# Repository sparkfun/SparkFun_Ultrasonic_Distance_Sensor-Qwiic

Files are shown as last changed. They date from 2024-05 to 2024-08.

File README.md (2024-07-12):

SparkFun Ultrasonic Distance Sensor - TCT40 (Qwiic) 
========================================

<center>SparkFun Ultrasonic Distance Sensor - TCT40 (Qwiic)</center>

[*SparkFun Ultrasonic Distance Sensor - TCT40 (Qwiic) (SEN-24805)*](https://www.sparkfun.com/products/24805)

The SparkFun Qwiic Ultrasonic Distance Sensor, a user-friendly upgrade to the popular HC-SR04 sensor, offers non-contact distance measurement from 2cm to 400cm with an accuracy of 3mm. This sensor is designed to seamlessly integrate with the Qwiic ecosystem for I<sup>2</sup>C communication, making it a breeze to add to your existing projects and daisy-chain with other Qwiic components.

If you prefer to bypass the Qwiic connector and I2C, you can also access the VCC, Trigger, Echo, and Ground pins broken out on the board's edge. Please be aware that this ultrasonic sensor comes uncalibrated, and you will need to manipulate the raw output for your specific application.

With its wide range of applications, the SparkFun Qwiic Ultrasonic Distance Sensor is a versatile tool for robotics projects, obstacle avoidance systems, and any application that requires accurate distance measurement without physical contact. Its adaptability makes it a valuable addition to your toolkit.

Repository Contents
-------------------

* **/Documentation** - Datasheets, additional product information
* **/Enclosure** - Enclosure files 
* **/Firmware** - Default firmware on the Ultrasonic Distance Sensor -TCT40 
* **/Hardware** - Eagle design files (.brd, .sch)
* **/Production** - Production panel files (.brd)

Documentation
--------------
* **[Hookup Guide](https://docs.sparkfun.com/SparkFun_Ultrasonic_Distance_Sensor-Qwiic)** - Basic hookup guide for the SparkFun Ultrasonic Distance Sensor - TCT40 (Qwiic).
* **[Arduino Library](https://github.com/sparkfun/SparkFun_Qwiic_Ultrasonic_Arduino_Library)** - Arduino library for the SparkFun Ultrasonic Distance Sensor - TCT40 (Qwiic). 

License Information
-------------------

This product is _**open source**_! 

Please review the LICENSE.md file for license information. 

If you have any questions or concerns on licensing, please contact technical support on our [SparkFun forums](https://forum.sparkfun.com/viewforum.php?f=152).

Distributed as-is; no warranty is given.

- Your friends at SparkFun.

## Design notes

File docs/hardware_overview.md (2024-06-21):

---
icon: material/cog
---

Overall Features:

* Operating Voltage 3.3V
* Detecting Angle: 80 degrees
* Sensor range: 2cm to 400cm
* MCU on board: STM8L051F3
* 7 bit Unshifted Address: 0x2F
* Dimensions: 1.75" x 0.85"

## STM8L051F3 MCU

The 8-bit ultra-low power STM8 MCU Core provides increased processing power (up to 16 MIPS at 16 MHz) while maintaining the advantages of a CISC architecture with improved code density, a 24-bit linear addressing space and an optimized architecture for low power operations. It also features embedded data EEPROM and low power, low-voltage, single-supply program Flash memory. The device incorporates an extensive range of enhanced I/Os and peripherals, a 12-bit ADC, a real-time clock, two 16-bit timers, one 8-bit timer, as well as standard communication interfaces such as an SPI, an I<sup>2</sup>C interface, and one USART. For more information, refer to the [datasheet](assets/component_documentation/stm8l051f3-1.pdf).

<figure markdown>
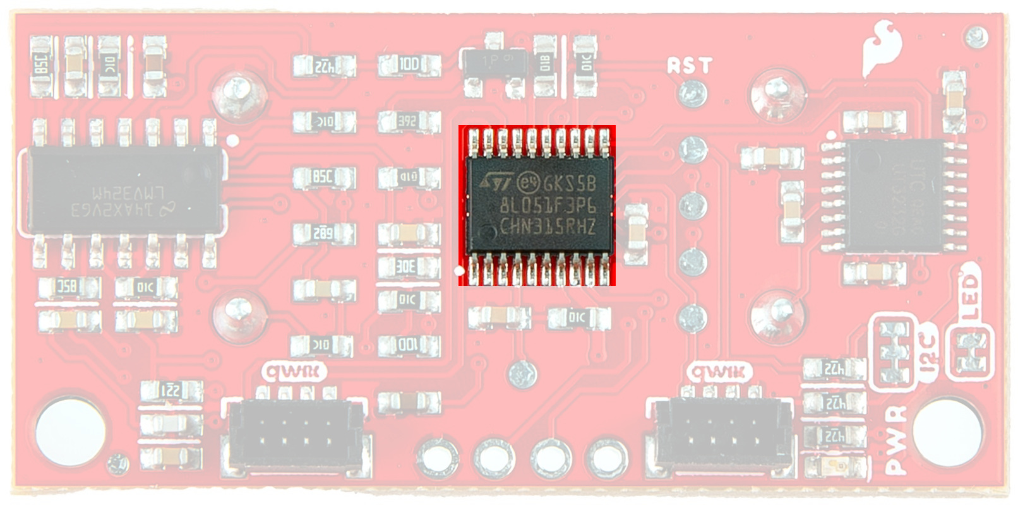
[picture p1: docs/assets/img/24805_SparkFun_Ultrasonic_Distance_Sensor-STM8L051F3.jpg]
STM8L051F3 MCU

<figcaption markdown>STM8L051F3 MCU</figcaption>
</figure>

## TCT40-16R/T

The TCT40-16R and TCT40-16T are an analog ultrasonic receiver and transmitter featuring a distance range from 2cm to 400cm meters and a beam angle of 80°. We've attached an RS232 transceiver to the transmitter to boost the signal being sent out, and the receiver goes through an LMV324 op-amp to clean up the signal coming in for optimum detection. For more information, refer to the translated datasheet [here](assets/component_documentation/TCT40-16-T-R.pdf).

<figure markdown>
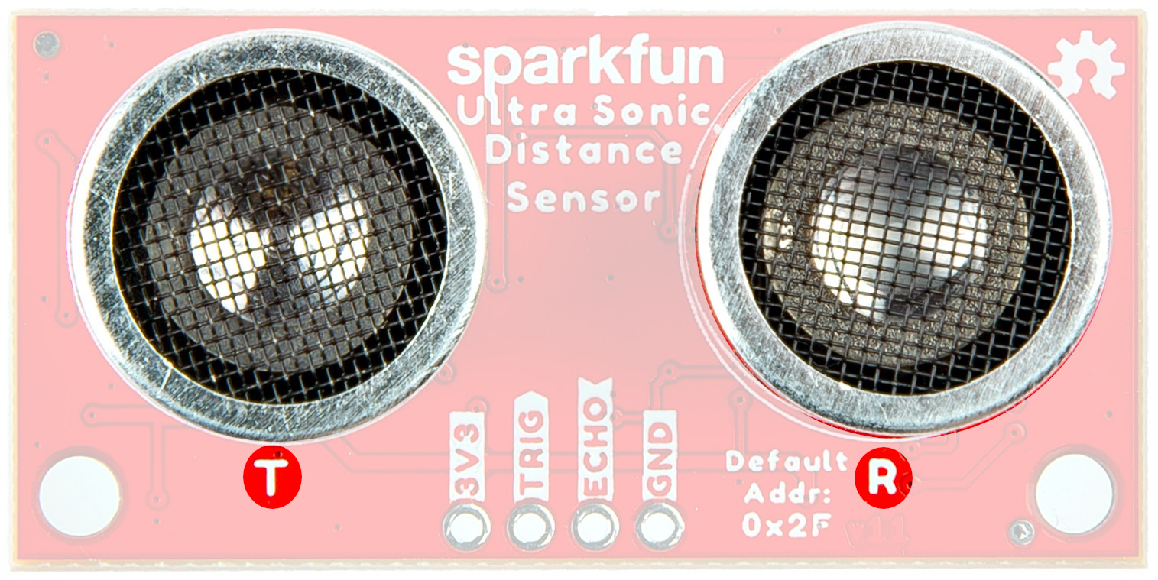
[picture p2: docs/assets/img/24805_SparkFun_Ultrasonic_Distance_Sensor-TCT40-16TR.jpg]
TCT40-16R/T

<figcaption markdown>TCT40-16R/T</figcaption>
</figure>

## Qwiic connectors

Our Qwiic Ecosystem makes sensors pretty much plug and play. There are two Qwiic connectors on the side of the Qwiic Distance Sensor board to provide power and I<sup>2</sup>C connectivity simultaneously. The default I<sup>2</sup>C address is 0x2F. The `updateAddress()` function allows you to change the I<sup>2</sup>C address to any address from 0x08 to 0x7F. More information on our Qwiic Ecosystem [can be found here](https://www.sparkfun.com/qwiic).  

<figure markdown>
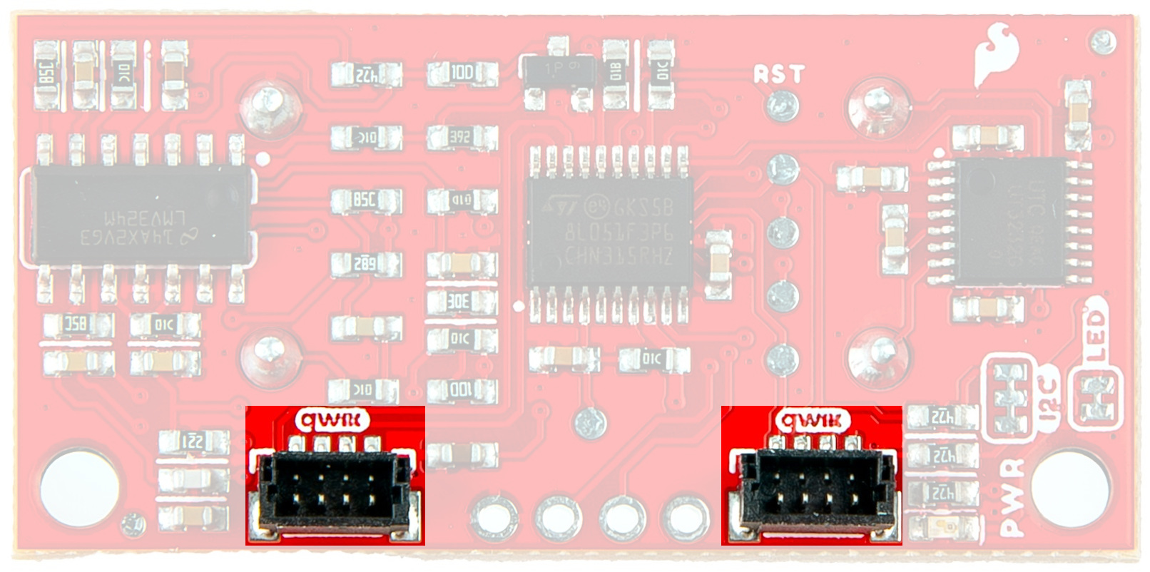
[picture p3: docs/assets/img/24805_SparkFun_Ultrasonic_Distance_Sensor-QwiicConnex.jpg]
Qwiic connectors

<figcaption markdown>Qwiic connectors</figcaption>
</figure>

## Power

Ideally, power will be supplied via the Qwiic connectors on either side of the board. Alternatively, power can be supplied through the pins along the bottom side of the board labeled `3V3` and `GND`. The input voltage range should be between <b>1.8</b>-<b>3.6V</b>. 

<figure markdown>
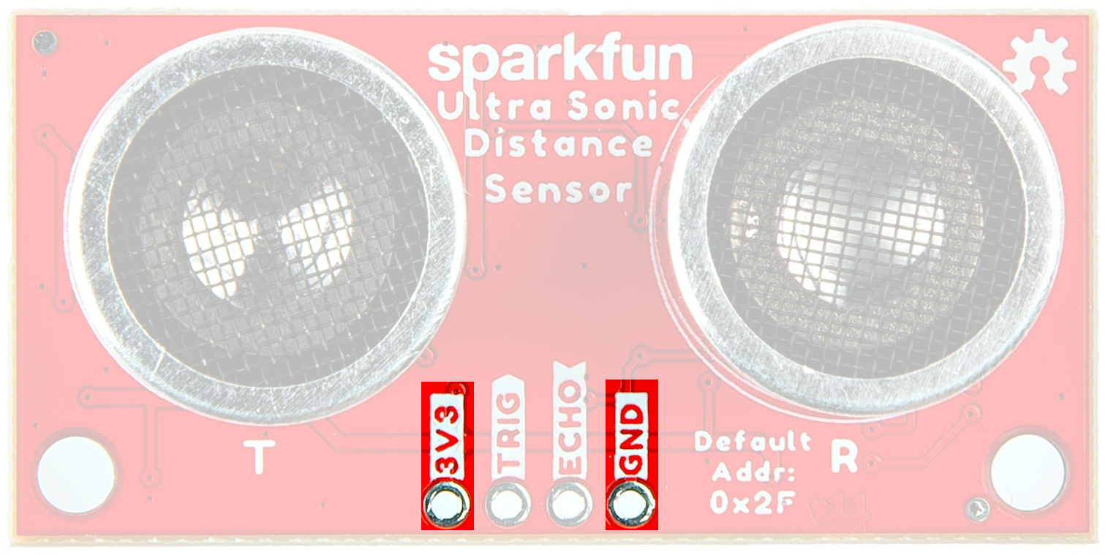
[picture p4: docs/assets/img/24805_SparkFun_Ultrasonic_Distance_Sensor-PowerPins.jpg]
Power Pins

<figcaption markdown>Power Pins</figcaption>
</figure>

## Trigger and Echo Pins

The Trigger and Echo pins are available as plated through holes to manually calculate the distance using the Ultrasonic Distance Sensor. To use, pull TRIG HIGH and then LOW, wait for the ECHO pin to go HIGH and then take the time in between to calculate the distance to the object. For more information on how this works, check out Example 3 in the [Arduino Library](https://github.com/sparkfun/SparkFun_Qwiic_Ultrasonic_Arduino_Library). 

<figure markdown>
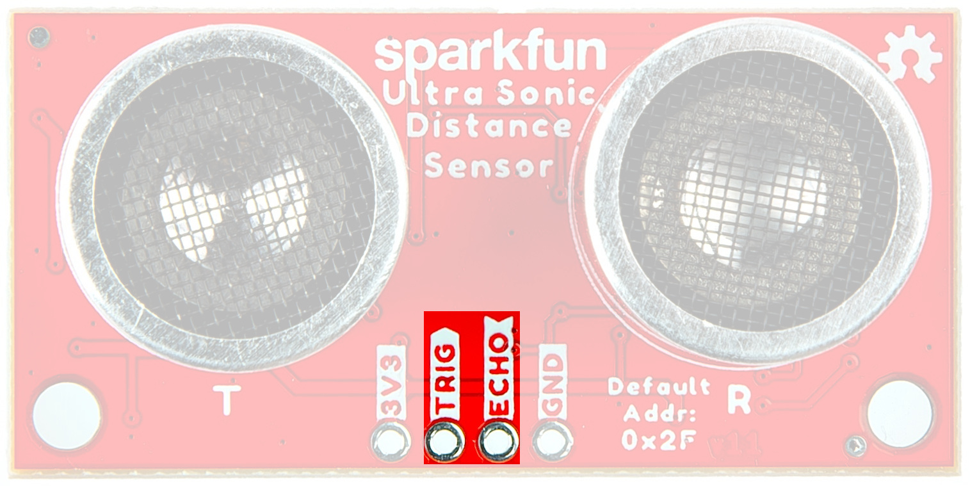
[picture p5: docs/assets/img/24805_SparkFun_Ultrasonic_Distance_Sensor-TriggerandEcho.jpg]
Trigger and Echo Pins

<figcaption markdown>Trigger and Echo Pins</figcaption>
</figure>

## Testpoint Pads

We've provided a number of open pads on the back of the board:

### I2C Pads

Should you wish to avoid using the Qwiic connectors, you can use these two pads (along with the power PTH pins) to still take advantage of the I<sup>2</sup>C communication protocols. 

<figure markdown>
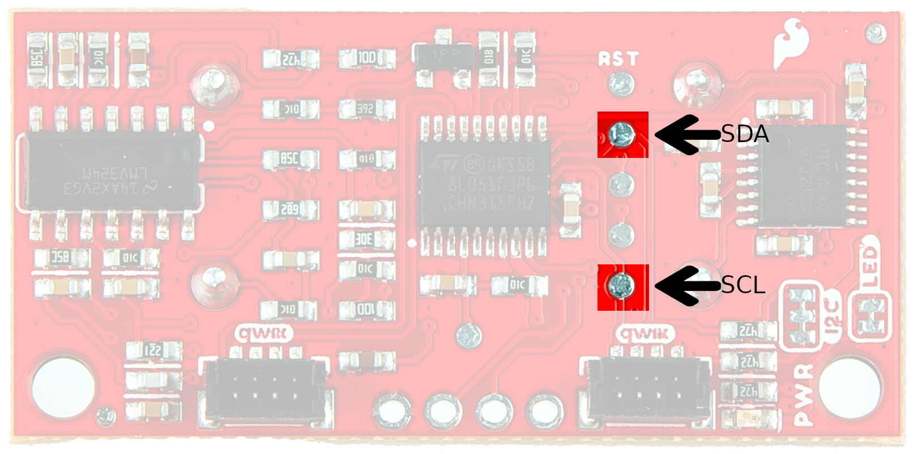
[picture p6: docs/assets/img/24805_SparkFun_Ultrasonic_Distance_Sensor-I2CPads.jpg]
I2C Testpoint Pads

<figcaption markdown>I<sup>2</sup>C Testpoint Pads</figcaption>
</figure>

### Single Wire Interface Module (SWIM)

SWIM, INT, and NRST are all part of the "Single Wire Interface Module (SWIM)" used for programming the onboard STM8 microcontroller and for most users, can be effectively ignored. For those who wish to dive into the deep end and tweak the firmware, these pads are available. Requirements include ST Visual Develop (the ST Progamming Software bundled with Visual Develop), a COSMIC compiler license, and a USB to SWIM adapter.

<figure markdown>
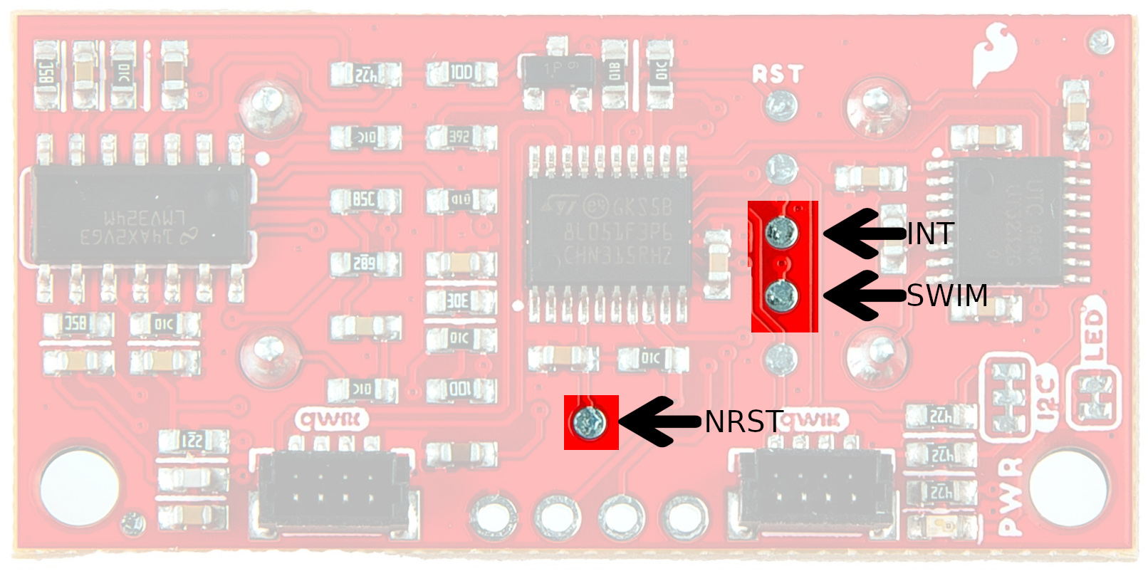
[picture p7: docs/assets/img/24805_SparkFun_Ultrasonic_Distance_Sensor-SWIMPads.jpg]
SWIM Testpoint Pads

<figcaption markdown>SWIM Testpoint Pads</figcaption>
</figure>

### ADDR_RST 

ADDR_RST resets the address to 0x2F. 

<figure markdown>
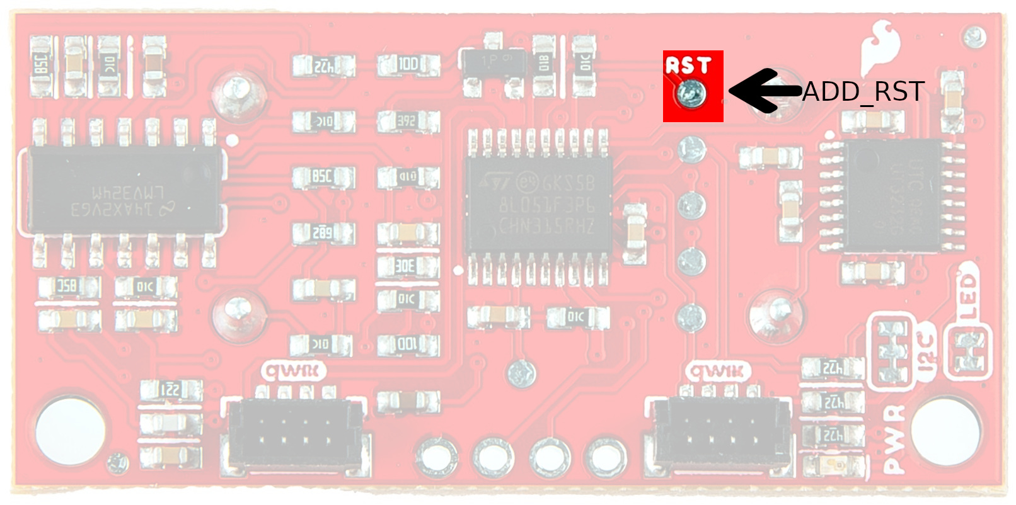
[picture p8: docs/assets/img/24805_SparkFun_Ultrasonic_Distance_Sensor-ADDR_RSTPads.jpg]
ADDR_RST Testpoint Pad

<figcaption markdown>ADDR_RST Testpoint Pad</figcaption>
</figure>

## Jumpers

??? note "Never modified a jumper before?"
	Check out our <a href="https://learn.sparkfun.com/tutorials/664">Jumper Pads and PCB Traces tutorial</a> for a quick introduction!
	<p align="center">
		<a href="https://learn.sparkfun.com/tutorials/664">
		Tutorial's thumbnail<br>
        How to Work with Jumper Pads and PCB Traces</a>
	</p>

### LED Jumper

If you are concerned about power consumption, need to run dark, or you just don't like LEDs, cut the traces here to disconnect the Power LED from, you guessed it, power. 

<figure markdown>
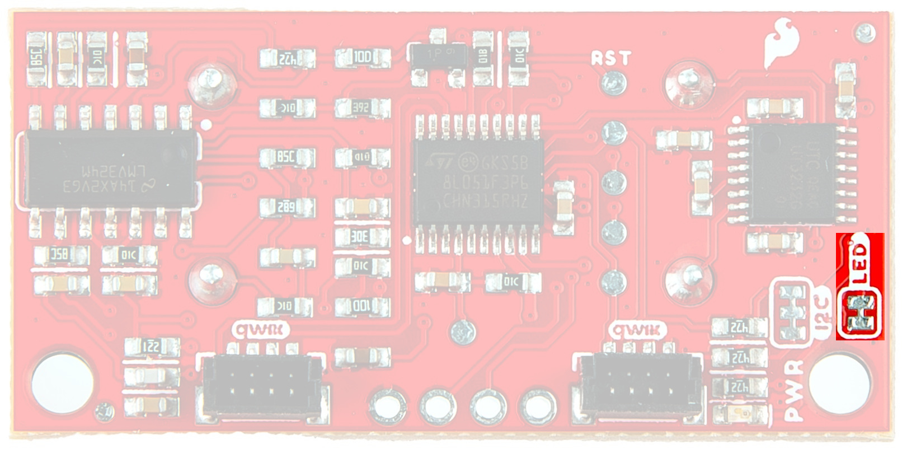
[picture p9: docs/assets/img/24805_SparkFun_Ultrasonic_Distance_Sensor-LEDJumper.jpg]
LED jumper

<figcaption markdown>LED Jumper</figcaption>
</figure>

### I<sup>2</sup>C

The Qwiic Ultrasonic Distance Sensor has built-in 2.2k pull-up resistors on the SDA and SCL lines. These are needed for normal I<sup>2</sup>C communication. The I<sup>2</sup>C jumper has two small traces connecting the pull-ups to 3.3V. **For general use you can leave this jumper unmodified.** If you have many (over 7) devices on the I<sup>2</sup>C bus, each with their own pull up resistors, then you may want to [cut the I<sup>2</sup>C jumpers](https://learn.sparkfun.com/tutorials/how-to-work-with-jumper-pads-and-pcb-traces) to disconnect the 2.2k resistors on each Qwiic board.

<figure markdown>
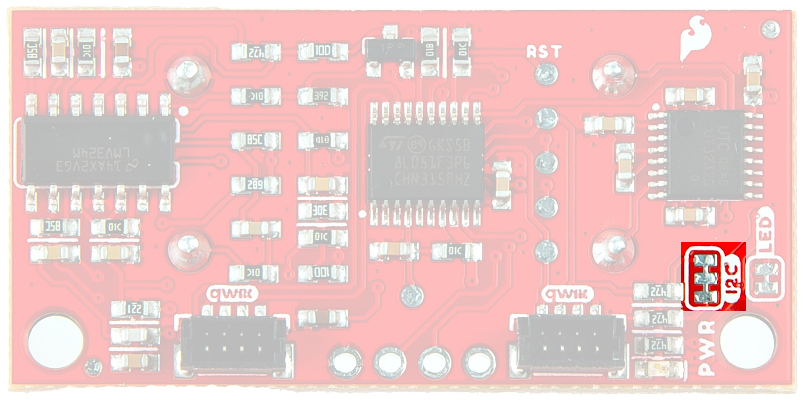
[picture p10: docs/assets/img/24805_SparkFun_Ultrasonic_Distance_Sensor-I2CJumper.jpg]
I2C jumper

<figcaption markdown>I<sup>2</sup>C jumper</figcaption>
</figure>

## Board Dimensions

The board dimensions are illustrated in the drawing below; the listed measurements are in inches.

<figure markdown>
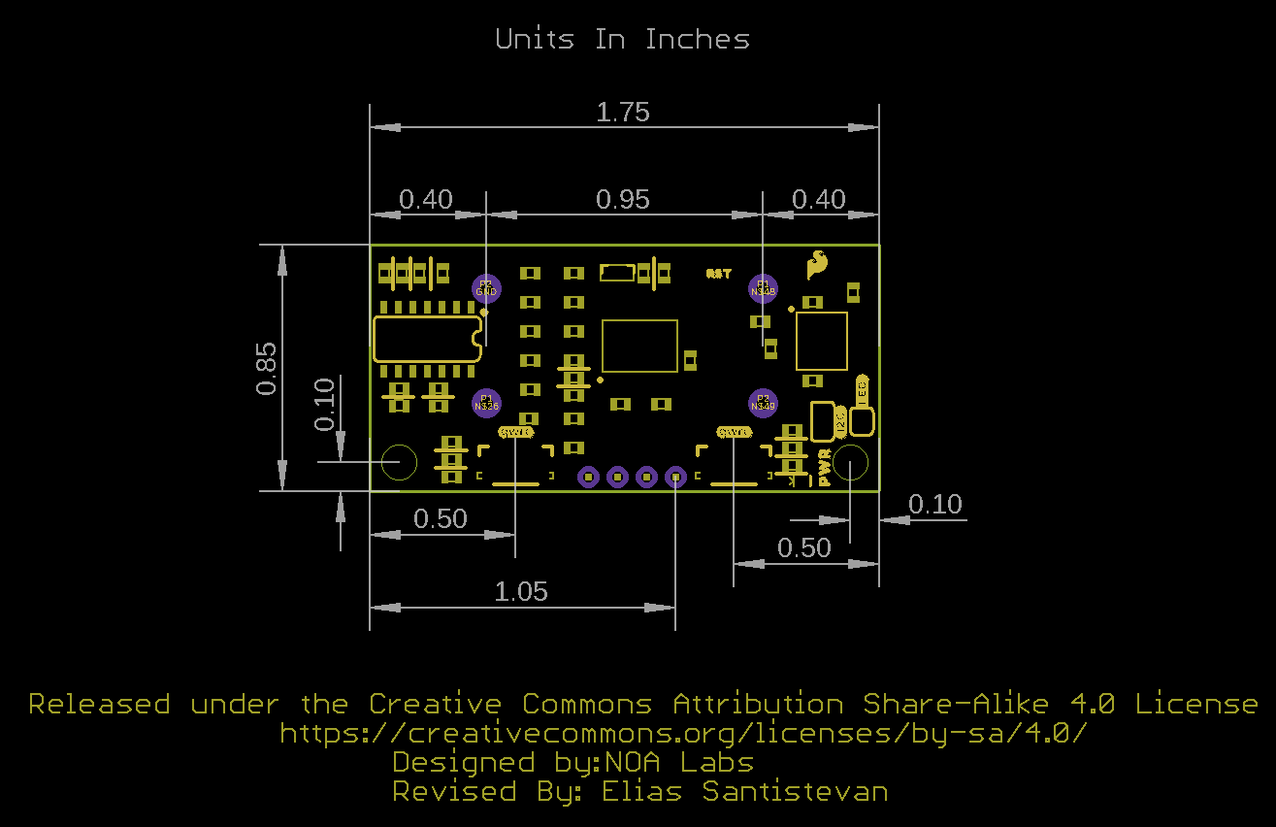
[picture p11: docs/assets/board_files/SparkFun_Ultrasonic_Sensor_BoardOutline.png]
Board measures 1.75" by 0.85"

<figcaption markdown>SparkFun Ultrasonic Sensor Board Dimensions</figcaption>
</figure>

??? tip "Need more measurements?"
	For more information about the board's dimensions, users can download the [Eagle files](SparkFun_Ultrasonic_Sensor_EagleFiles.zip). These files can be opened in Eagle and additional measurements can be made with the dimensions tool.

	??? info ":octicons-download-16:{ .heart } Eagle - Free Download!"
		Eagle is a [CAD]("computer-aided design") program for electronics that is free to use for hobbyists and students. However, it does require an account registration to utilize the software.

		<center>
		[Download from<br>:autodesk-primary:{ .autodesk }](https://www.autodesk.com/products/eagle/free-download "Go to downloads page"){ .md-button .md-button--primary width="250px" }
		</center>
	
	??? info ":straight_ruler: Dimensions Tool"
		This video from Autodesk demonstrates how to utilize the dimensions tool in Eagle, to include additional measurements:

		<center>
		<div class="video">
		<iframe src="https://www.youtube.com/embed/dZLNd1FtNB8" title="EAGLE Dimension Tool" frameborder="0" allow="accelerometer; autoplay; clipboard-write; encrypted-media; gyroscope; picture-in-picture" allowfullscreen></iframe>
		</div>
		</center>

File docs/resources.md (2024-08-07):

<!-- This section should include all the relevant documentation and product files (Eagle files, schematic, datasheet(s), landing pages, etc. and any relevant tutorials to go beyond the Hookup Guide.) -->

For more resources related to the SparkFun Ultrasonic Distance Sensor - TCT40 (Qwiic), check out the links listed here: 

* [Product Page](https://www.sparkfun.com/products/24805)
* [Schematic](assets/board_files/SparkFun_Ultrasonic_Sensor_Schematic.pdf) (PDF)
* [Eagle Files](assets/board_files/SparkFun_Ultrasonic_Sensor_EagleFiles.zip) (ZIP)
* [Board Dimensions](assets/board_files/SparkFun_Ultrasonic_Sensor_BoardOutline.png) (PDF)
* Component Documentation
    * [STM8L051F3 MCU Datasheet](assets/component_documentation/stm8l051f3-1.pdf) (PDF)
    * [TCT40-16R/T Datasheet](assets/component_documentation/TCT40-16-T-R.pdf) (PDF)
    * [RS232 transceiver Datasheet](assets/component_documentation/sp3222eb_sp3232eb.pdf) (PDF)
* [Arduino Library GitHub Repository](https://github.com/sparkfun/SparkFun_Qwiic_Ultrasonic_Arduino_Library)
* [GitHub Hardware Respository](https://github.com/sparkfun/SparkFun_Ultrasonic_Distance_Sensor-Qwiic/)

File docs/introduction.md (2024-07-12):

---
icon: material/book-open-page-variant
---

<div class="grid cards desc" markdown>

-    <a href="https://www.sparkfun.com/products/24805">
    **SparkFun Ultrasonic Distance Sensor - TCT40 (Qwiic)**<br>
    **SKU:** SEN-24805

    ---

    <figure markdown>
    Product Thumbnail
    </figure></a>

-    The SparkFun Qwiic Ultrasonic Distance Sensor, a user-friendly upgrade to the popular HC-SR04 sensor, offers non-contact distance measurement from 2cm to 400cm with an accuracy of 3mm. This sensor is designed to seamlessly integrate with the Qwiic ecosystem for I<sup>2</sup>C communication, making it a breeze to add to your existing projects and daisy-chain with other Qwiic components.

    With its wide range of applications, the SparkFun Qwiic Ultrasonic Distance Sensor is a versatile tool for robotics projects, obstacle avoidance systems, and any application that requires accurate distance measurement without physical contact. Its adaptability makes it a valuable addition to your toolkit.

    <center>
    [Purchase from SparkFun :fontawesome-solid-cart-plus:{ .heart }](https://www.sparkfun.com/products/24805){ .md-button .md-button--primary }
    </center>

</div>

## Required Materials

To follow along with this tutorial, you will need the following materials. You may not need everything though depending on what you have. Add it to your cart, read through the guide, and adjust the cart as necessary.

<table style="border-style:none">
    <tr>
        <td>
            <a href="https://www.sparkfun.com/products/24805">
                <center>SparkFun Ultrasonic Distance Sensor - TCT40 (Qwiic)</center>
                <h3 class="title">SparkFun Ultrasonic<br /> Distance Sensor - TCT40<br />(Qwiic)</h3>
            </a>
            SEN-24805
        </td>
        <td>
            <a href=" https://www.sparkfun.com/products/10215">
                <center>USB micro-B Cable - 6 Foot</center>
                <h3 class="title">USB micro-B Cable - 6 Foot</h3>
            </a>
            CAB-10215
        </td>
<!--        <td>
            <a href="https://www.sparkfun.com/products/17153">
                <center><img src="https://cdn.sparkfun.com//assets/parts/1/6/1/3/5/17153-SparkFun_Qwiic_OLED_Display__0.91_in__128x32_-05.jpg" style="width:140px; height:140px; object-fit:contain;" alt="SparkFun Qwiic OLED Display (0.91 in., 128x32)" >
                </center>
                <h3 class="title">SparkFun Qwiic OLED Display (0.91 in., 128x32)</h3>
            </a>
            LCD-17153
        </td>-->
        <td>
            <a href="https://www.sparkfun.com/products/14427">
                <center>Qwiic Cable - 100mm
                </center>
                <h3 class="title">Qwiic Cable - 100mm</h3>
            </a>
            PRT-14427
        </td>
        <td>
            <a href="https://www.sparkfun.com/products/15123">
                <center>SparkFun RedBoard Qwiic
                </center>
                <h3 class="title">SparkFun RedBoard Qwiic</h3>
            </a>
            DEV-15123
        </td>
    </tr>
</table>

## Suggested Reading

Below are a few tutorials that may help users familiarize themselves with various aspects of the board.

<div class="grid cards hide col-4" markdown align="center">

-   <a href="https://learn.sparkfun.com/tutorials/how-to-solder-through-hole-soldering">
    <figure markdown>
    How to Solder: Through-Hole Soldering
    </figure>
    </a>
    <a href="https://learn.sparkfun.com/tutorials/how-to-solder-through-hole-soldering">**How to Solder: Through-Hole Soldering**
    </a>

-   <a href="https://learn.sparkfun.com/tutorials/82">
    <figure markdown>
    I2C
    </figure>
    </a>
    <a href="https://learn.sparkfun.com/tutorials/82">**I2C**
    </a>

-   <a href="https://learn.sparkfun.com/tutorials/terminal-basics">
    <figure markdown>
    SPI
    </figure>
    </a>
    <a href="https://learn.sparkfun.com/tutorials/terminal-basics">**Serial Terminal Basics**
    </a>
</div>

<center>
<div align="center">
    <div style="top:5px;left:5px;background-color:Gray;position:relative">
        <div style="top:-5px;left:-5px;background-color:#ffffff;position:relative;border:1px solid black;">
            <a href="https://www.sparkfun.com/qwiic">Qwiic Connect System</a>
        </div>
    </div>
</div>
</center>

The SparkFun Ultrasonic Distance Sensor - TCT40 (Qwiic) takes advantage of the [Qwiic connect system](https://www.sparkfun.com/qwiic). We recommend familiarizing yourself with the **Logic Levels** and **I<sup>2</sup>C** tutorials.  Click on the banner above to learn more about [Qwiic products](https://www.sparkfun.com/qwiic).

<center>
    <iframe width="600" height="327" src="https://www.youtube.com/embed/x0RDEHqFIF8" title="SparkFun's Qwiic Connect System" frameborder="0" allow="accelerometer; autoplay; clipboard-write; encrypted-media; gyroscope; picture-in-picture" allowfullscreen></iframe>
</center>

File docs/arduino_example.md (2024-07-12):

---
icon: simple/arduino
---

Now that we've installed the Arduino library, it's time to upload our first sketch to make sure everything is working properly.

###Example 1

This first example just does some basic measurements. To find Example 1, go to **File** > **Examples** > **SparkFun Qwiic Ultrasonic Arduino Library** > **Example1_BasicReadings**:

<figure markdown>
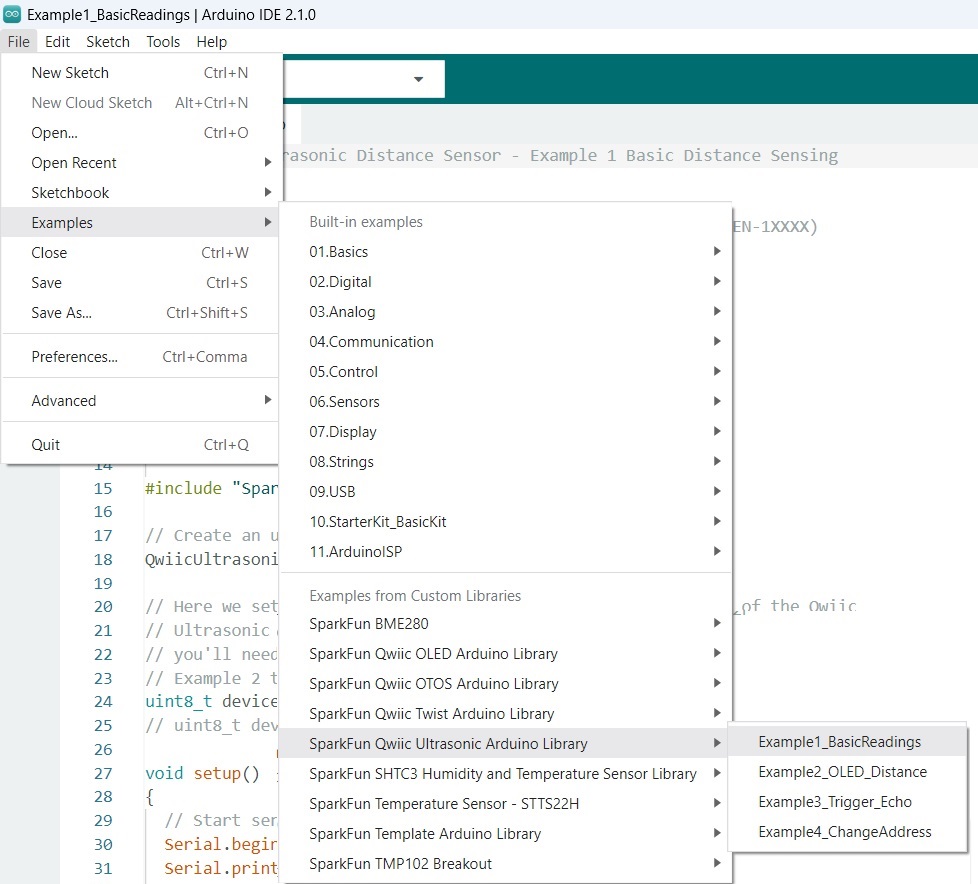
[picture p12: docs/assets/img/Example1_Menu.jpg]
Ultrasonic Arduino Example 1

<figcaption markdown>Finding Example 1</figcaption>
</figure>

Alternatively, you can expand the link below and copy and paste the code into a shiny new Arduino sketch:

??? "Example 1 Arduino Code"
	```
	--8<-- "https://raw.githubusercontent.com/sparkfun/SparkFun_Qwiic_Ultrasonic_Arduino_Library/main/examples/Example1_BasicReadings/Example1_BasicReadings.ino"
	```

Make sure you've selected the correct board and port in the Tools menu and then hit the upload button. Once the code has finished uploading, go ahead and open a [Serial Monitor](https://learn.sparkfun.com/tutorials/terminal-basics). You should see something similar to the following.

<figure markdown>
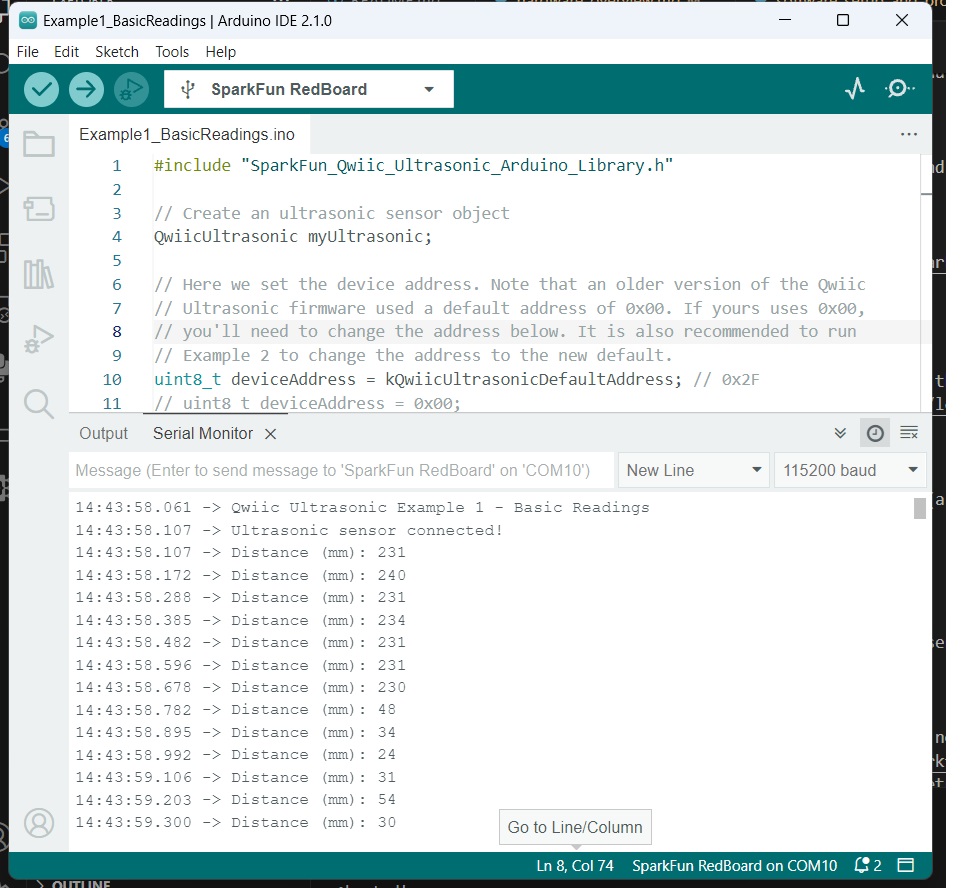
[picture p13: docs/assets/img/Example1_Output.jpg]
Ultrasonic Distance Sensor Arduino Example 1 Output

<figcaption markdown>Example 1 Output</figcaption>
</figure>

Note the output change when the mouse is moved closer to the sensor.

### Example 2

Let's add in an LCD screen to display our measurements. For this example you will need another [Qwiic Cable](https://www.sparkfun.com/products/14427) and the [SparkFun Qwiic OLED Display (0.91 in., 128x32)](https://www.sparkfun.com/products/24606).

To display the sensor readings on the connected Qwiic OLED, we will need to install the SparkFun Qwiic OLED library. You can install this library to automatically in the Arduino IDE's Library Manager by searching for "**SparkFun Qwiic OLED**". Or you can manually download it from the [GitHub repository](https://github.com/sparkfun/SparkFun_Qwiic_OLED_Arduino_Library).

<center>
	[Download the SparkFun Qwiic OLED Library (ZIP)](https://github.com/sparkfun/SparkFun_Qwiic_OLED_Arduino_Library/archive/refs/heads/main.zip){ .md-button .md-button--primary }
</center>

To find Example 2, go to **File** > **Examples** > **SparkFun Qwiic Ultrasonic Arduino Library** > **Example2_OLED_Distance**:

<figure markdown>
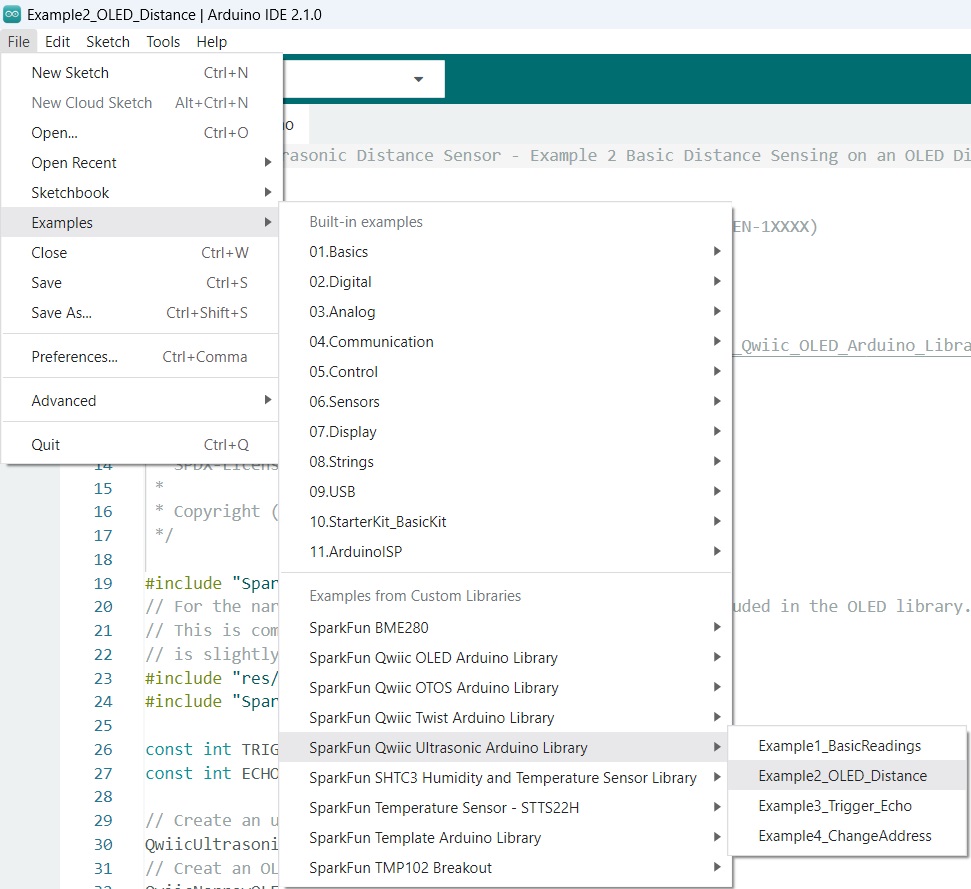
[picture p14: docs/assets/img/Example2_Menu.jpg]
Ultrasonic Arduino Example 2

<figcaption markdown>Finding Example 2</figcaption>
</figure>

Alternatively, you can expand the link below and copy and paste the code into a shiny new Arduino sketch:

??? "Example 2 Arduino Code"
	```
	--8<-- "https://raw.githubusercontent.com/sparkfun/SparkFun_Qwiic_Ultrasonic_Arduino_Library/main/examples/Example2_OLED_Distance/Example2_OLED_Distance.ino"
	```

We have code, now let's hookup the hardware! The Qwiic system makes this example quite literally plug and play. Use Qwiic cables to make your hardware setup look like this:

<figure markdown>
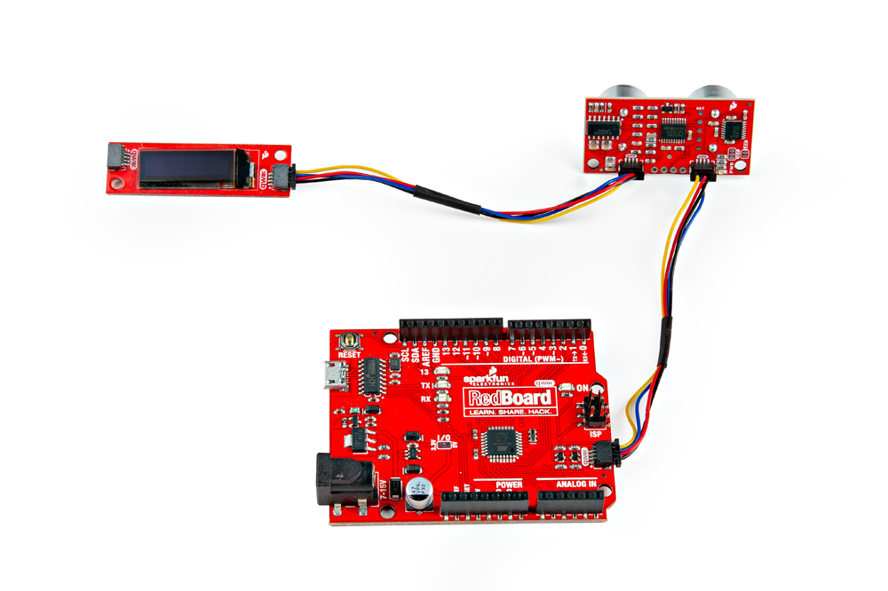
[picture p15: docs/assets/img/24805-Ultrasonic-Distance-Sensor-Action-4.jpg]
Example 2 Hardware Hookup

<figcaption markdown>Example 2 Hardware Hookup</figcaption>
</figure>

Make sure you've selected the correct board and port in the Tools menu and then hit the upload button. Once the code has finished uploading, you should see something similar to the following.

<figure markdown>
Oh no! A dinosaur is approaching distance sensor and now it's only 61mm away!
<figcaption markdown>Run away!</figcaption>
</figure>

Try moving an object (like your hand or a dinosaur) closer to the sensor - notice the output of the OLED shows you how close the object is! Grr. Rawr!

### Going Further

There are more examples in the Arduino Library that allow you to change the I<sup>2</sup>C address or use the Trigger and Echo Pins. Feel free to check them out!

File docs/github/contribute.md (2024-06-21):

# Contribute: Make an Augmentation!
Spot an improvement opportunity? Feel free to contribute to our open-source design and documentation. 

## :material-file-document-multiple:&nbsp;Improve our Documentation
All of this documentation can be modified by you! Please help us make it better.

* These pages are contained in the [`docs` folder](https://github.com/sparkfun/SparkFun_Ultrasonic_Distance_Sensor-Qwiic/tree/v11_Firmware_v01/docs) of the [SparkFun Ultrasonic Distance Sensor - TCT40 (Qwiic) repository](https://github.com/sparkfun/SparkFun_Ultrasonic_Distance_Sensor-Qwiic/tree/v11_Firmware_v01).

<!-- ### :material-source-pull:&nbsp;Submit a Correction -->
### Submit a Correction

1. With a GitHub account, [fork this repository](https://github.com/sparkfun/SparkFun_Ultrasonic_Distance_Sensor-Qwiic/fork).
2. Add your corrections or improvements to the markdown file.
3. File a pull request with your changes, and enjoy making the ~~words~~ ~~worlds~~ world a better place.
	* Once received, the documentation specialist will automatically be notified.
	* We will review your suggested improvements to make sure they are correct and fit within our documentation standards.

## :material-cog:&nbsp;Improve our Hardware Design
All of our designs are open-source! Please help us make it better.

* Our board design files are contained in the [`Hardware` folder](https://github.com/sparkfun/SparkFun_Ultrasonic_Distance_Sensor-Qwiic/tree/v11_Firmware_v01/Hardware) of the [SparkFun Ultrasonic Distance Sensor - TCT40 (Qwiic) repository](https://github.com/sparkfun/SparkFun_Ultrasonic_Distance_Sensor-Qwiic/tree/v11_Firmware_v01).

<!-- ### :material-source-pull:&nbsp;Submit a Design Enhancement -->
### Submit a Design Enhancement

1. With a GitHub account, [fork this repository](https://github.com/sparkfun/SparkFun_Ultrasonic_Distance_Sensor-Qwiic/fork).
2. Add your design augmentation(s)
3. File a pull request with your changes, and enjoy making the ~~words~~ ~~worlds~~ world a better place.
	1. Once received, the engineer in charge of the original design will automatically be notified.
	2. We will review your suggested improvement(s) to verify that they are within our board design standards and meet our product design requirements.
	3. If approved, we will flag these changes for our next board revision. Congrats! 🍻

		!!! info
			Even if your suggestion is accepted, these changes may not be immediately available for purchase. We may have to cycle through our current product inventory first.

## Contributors&nbsp;:clap:
Let's provide some recognition to the contributors for this project!

GitHub Contributors Image
<br>


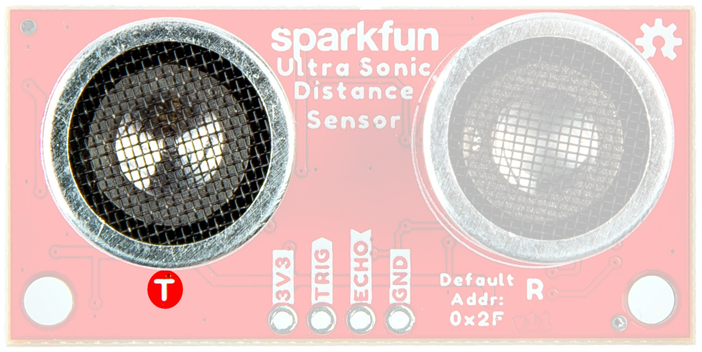
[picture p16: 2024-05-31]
docs/assets/img/24805_SparkFun_Ultrasonic_Distance_Sensor-Transmit.jpg

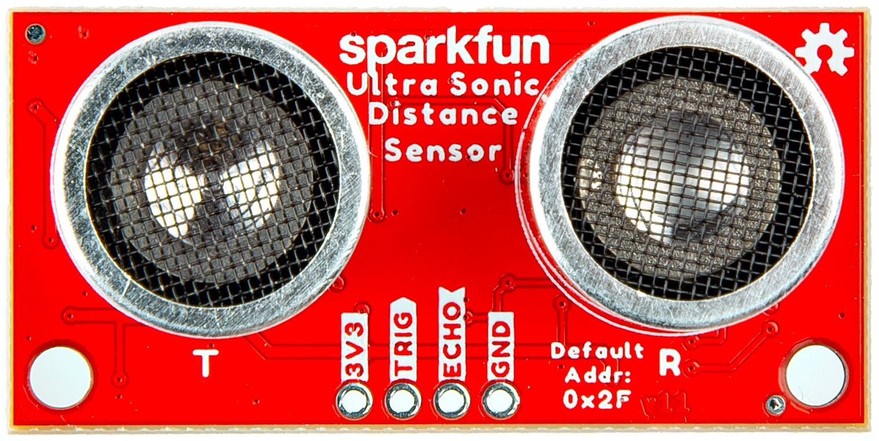
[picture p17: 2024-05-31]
docs/assets/img/SEN-24805-Ultrasonic-Distance-Sensor-Front-High-Res.jpg

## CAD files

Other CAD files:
Firmware/firmware_v01.stp

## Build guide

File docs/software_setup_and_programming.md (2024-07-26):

---
icon: simple/arduino
---

!!! attention
	If this is your first time using Arduino, please review our tutorial on [installing the Arduino IDE](https://learn.sparkfun.com/tutorials/installing-arduino-ide). If you have not previously installed an Arduino library, please check out our [installation guide](https://learn.sparkfun.com/tutorials/installing-an-arduino-library).

SparkFun has written a library to work with the SparkFun Ultrasonic Distance Sensor Qwiic Board. You can obtain this library <!--through the Arduino Library Manager by searching for "Ultrasonic" and installing the latest version. If you prefer--> by clicking on the button below, or by downloading it from the [GitHub Repository](https://github.com/sparkfun/SparkFun_Qwiic_Ultrasonic_Arduino_Library).

<center>
	[SparkFun Ultrasonic Distance Sensor Qwiic Arduino Library GitHub](https://github.com/sparkfun/SparkFun_Qwiic_Ultrasonic_Arduino_Library/archive/refs/heads/main.zip){ .md-button .md-button--primary }
</center>

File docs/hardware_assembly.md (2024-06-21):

---
icon: fontawesome/solid/screwdriver-wrench
---

Using the Qwiic system, assembling the hardware is simple. Connect the RedBoard to one of the Ultrasonic Distance Sensor Qwiic ports using your Qwiic cables. Then connect the RedBoard to your computer via the MicroUSB cable and voila! You're ready to rock! 

<figure markdown>
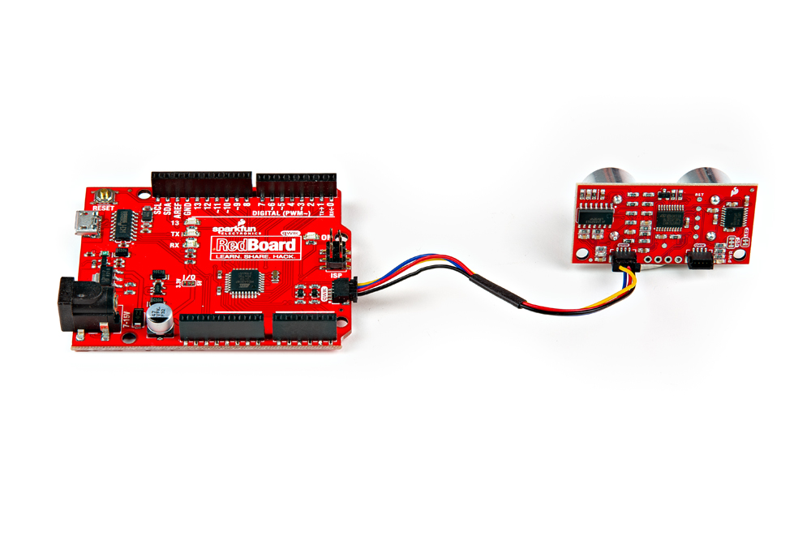
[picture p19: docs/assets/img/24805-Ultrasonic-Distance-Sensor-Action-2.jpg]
Ultrasonic Distance Sensor Connected to Programming

<figcaption markdown>Ultrasonic Distance Sensor Connected to Programming</figcaption>
</figure>

If you don't want to use the Qwiic system, there are Plated Through Holes on the side of the board that you can solder headers to. 

??? note "New to soldering?"
	If you have never soldered before or need a quick refresher, check out our [How to Solder: Through-Hole Soldering](https://learn.sparkfun.com/tutorials/how-to-solder-through-hole-soldering) guide.

	<div class="grid cards col-4" markdown  align="center">

	-   <a href="https://learn.sparkfun.com/tutorials/5">
		<figure markdown>
		Tutorial thumbnail
		</figure>

		---
		
		**How to Solder: Through-Hole Soldering**</a>

	</div>

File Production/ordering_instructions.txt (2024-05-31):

panel size, 104x190mm
PCB thickness, 1.6mm
number of layers, 2
soldermask color, Red
silkscreen color, White
oz copper, 1oz
finish, HASL lead free
stencils, top
pcs per panel, 16
min trace width, 0.2032mm / 0.0080in
min drill size, 0.3048mm / 0.0120in

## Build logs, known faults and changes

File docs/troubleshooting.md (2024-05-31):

---
icon: fontawesome/solid/question
---

!!! note
    <span class="glyphicon glyphicon-question-sign" aria-hidden="true"></span>
        <strong> Not working as expected and need help? </strong> <br /><br />

    If you need technical assistance and more information on a product that is not working as you expected, we recommend heading on over to the <a href="https://www.sparkfun.com/technical_assistance">SparkFun Technical Assistance</a> page for some initial troubleshooting. <br /><br />

    <div style="text-align: center"><a href="https://www.sparkfun.com/technical_assistance" target="sfe_technical_assistance" class="md-button">SparkFun Technical Assistance Page</a></div>

    If you don't find what you need there, the <a href="https://forum.sparkfun.com/index.php">SparkFun Forums</a> are a great place to find and ask for help. If this is your first visit, you'll need to <a href="https://forum.sparkfun.com/ucp.php?mode=register">create a Forum Account</a> to search product forums and post questions.<br /><br />

    <div style="text-align: center"><a href="https://forum.sparkfun.com/ucp.php?mode=register" class="md-button">Create New Forum Account</a>&nbsp;&nbsp;&nbsp;<a href="https://forum.sparkfun.com/index.php" class="md-button md-button--primary">Log Into SparkFun Forums</a></div>

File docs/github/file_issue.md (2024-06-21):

# Did we make a mistake?

Spot something wrong? Please let us know. 

<!-- Technical Assistance Box -->
!!! warning "Need Help?"
    If you need technical assistance or more information on a product that is not working as you expected, we recommend heading on over to the [SparkFun Technical Assistance](https://www.sparkfun.com/technical_assistanc) page for some initial troubleshooting. This **Submit Issues** page is not where users should seek assistance.

    <center>
    [SparkFun Technical Assistance Page](https://www.sparkfun.com/technical_assistance){ .md-button .md-button--primary }
    </center>
    
    If you can't find what you need there, the [SparkFun Forums](https://forum.sparkfun.com/index.php) is a great place to search the product forums and ask questions.
    
    !!! info "Account Registration Required"
        For your first visit to our forum, you'll need to create a [Forum Account](https://forum.sparkfun.com/ucp.php?mode=register) to post questions.

## Discrepancies in the Documentation

All of our documentation can be modified by you! Please help us make it better.

* The documentation files for these pages are contained in the [`docs` folder](https://github.com/sparkfun/SparkFun_Ultrasonic_Distance_Sensor-Qwiic/tree/v11_Firmware_v01/docs) of the [SparkFun Ultrasonic Distance Sensor - TCT40 (Qwiic) repository](https://github.com/sparkfun/SparkFun_Ultrasonic_Distance_Sensor-Qwiic/tree/v11_Firmware_v01).

### 🔍 Spot something wrong?

If a section of the documentation is incorrect, please [open an issue](https://github.com/sparkfun/SparkFun_Ultrasonic_Distance_Sensor-Qwiic/issues) and let us know.

### Do you have a suggested correction?

1. With a GitHub account, [fork this repository](https://github.com/sparkfun/SparkFun_Ultrasonic_Distance_Sensor-Qwiic/fork).
2. Add your correction(s) or improvement(s) to the markdown file(s)
3. File a pull request with your changes, and enjoy making the ~~words~~ ~~worlds~~ world a better place.
	* Once received, the documentation specialist will automatically be notified.
	* We will review your suggested improvement(s) to make sure they are correct and fit within our documentation standards.

## Problems in the Hardware Design

All of our designs are open-source! Please help us make it better.

* Our board design files are contained in the [`Hardware` folder](https://github.com/sparkfun/SparkFun_Ultrasonic_Distance_Sensor-Qwiic/tree/v11_Firmware_v01/Hardware) of the [SparkFun Ultrasonic Distance Sensor - TCT40 (Qwiic) repository](https://github.com/sparkfun/SparkFun_Ultrasonic_Distance_Sensor-Qwiic/tree/v11_Firmware_v01).

### Does something not make sense? 🤔

If part of the design is confusing, please [open an issue](https://github.com/sparkfun/SparkFun_Ultrasonic_Distance_Sensor-Qwiic/issues) and let us know.

### Did we forget to include an important function of the board? 🤦

If part of the board's functionality is missing, please [open an issue](https://github.com/sparkfun/SparkFun_Ultrasonic_Distance_Sensor-Qwiic/issues) and file a feature request.

!!! tip "Design Considerations"
	Please keep in mind that we may intentionally exclude certain functions of the board to meet our product design requirements.
	
	* *For example, our Qwiic Micro boards are intended to fit on a small board layout and only use I<sup>2</sup>C communication; therefore, we may not have the SPI and interrupt pins available for users.*

### Do you wish to contribute directly to improving the board design?

1. With a GitHub account, [fork this repository](https://github.com/sparkfun/SparkFun_Ultrasonic_Distance_Sensor-Qwiic/fork).
2. Add your design augmentation(s)
3. File a pull request with your changes, and enjoy making the ~~words~~ ~~worlds~~ world a better place.
	1. Once received, the engineer in charge of the original design will automatically be notified.
	2. We will review your suggested improvement(s) to verify that they are within our board design standards and meet our product design requirements.
	3. If approved, we will flag these changes for our next board revision. Congrats! 🍻

		!!! info
			Even if your suggestion is accepted, these changes may not be immediately available for purchase. We may have to cycle through our current product inventory first.

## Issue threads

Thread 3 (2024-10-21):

Ultrasonic hangs with certain processors

edspark, 2024-10-21:
Relevant information can be found [here in the forum post](https://community.sparkfun.com/t/tct40-ultrasonic-sensor-only-reads-0/61107). May be an issue with the firmware and it may not.

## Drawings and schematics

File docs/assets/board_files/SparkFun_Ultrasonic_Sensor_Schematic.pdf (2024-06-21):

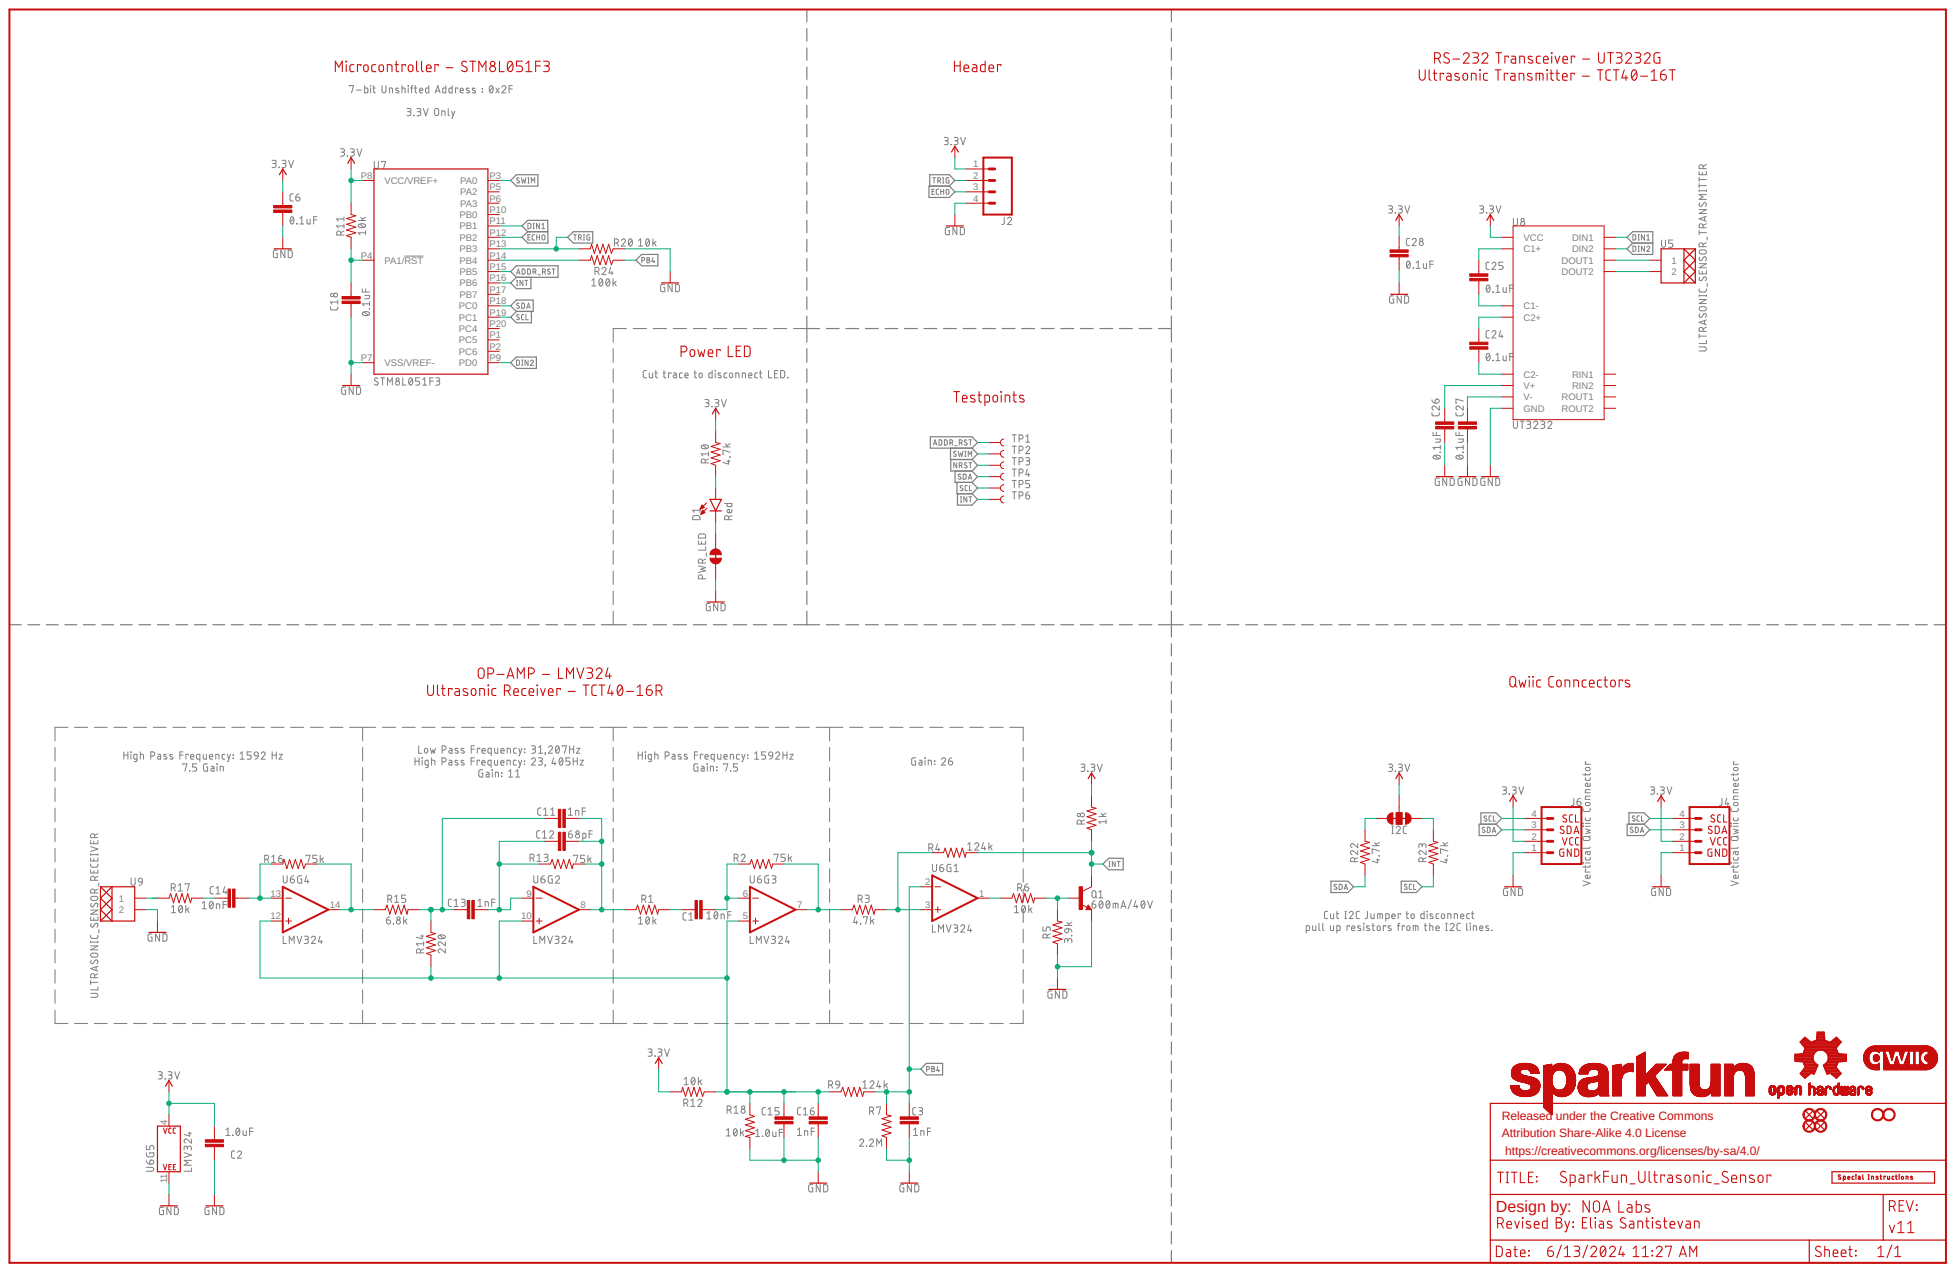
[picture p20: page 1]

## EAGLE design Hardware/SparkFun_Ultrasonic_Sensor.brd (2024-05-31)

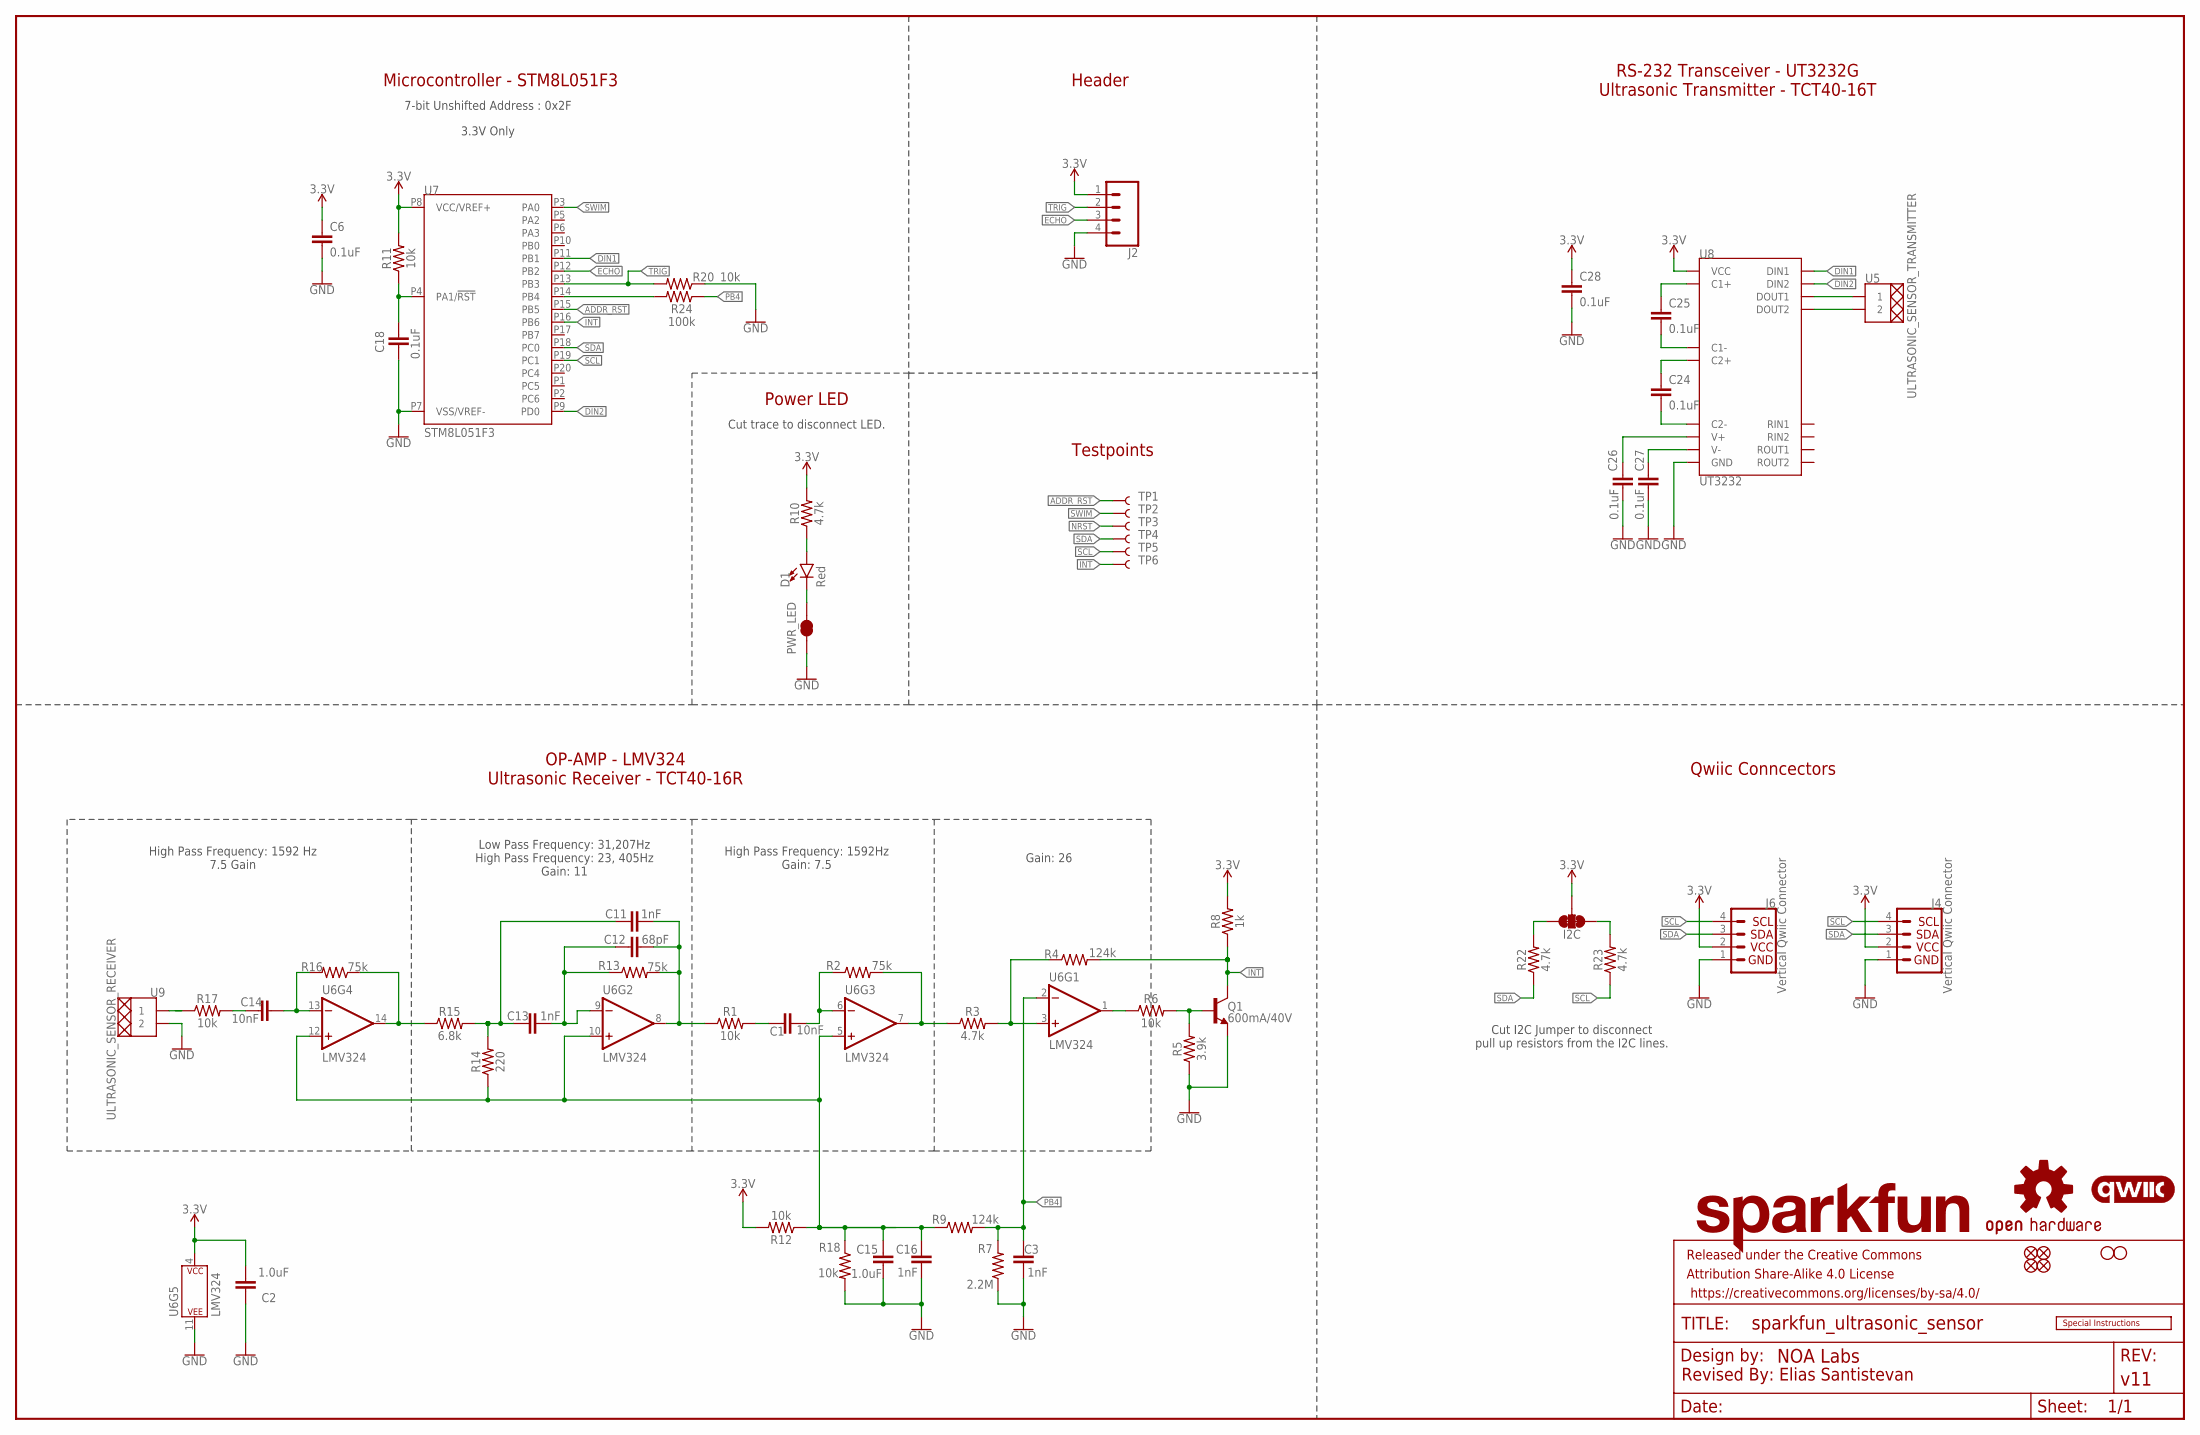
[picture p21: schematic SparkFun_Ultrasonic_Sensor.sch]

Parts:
C1, C14: 10nF; 0603
C2, C15: 1.0uF; 0603
C3, C11, C13, C16: 1nF; 0603
C6, C18, C24, C25, C26, C27, C28: 0.1uF; 0603
C12: 68pF; 0603
D1: Red; LED-0603
FD1, FD2, FD3, FD4: FIDUCIAL1X2; FIDUCIAL-1X2
FRAME1: FRAME-LEDGER; CREATIVE_COMMONS
H1, H2: STAND-OFFTIGHT; STAND-OFF-TIGHT
I2C: JUMPER-SMT_3_2-NC_TRACE_SILK; SMT-JUMPER_3_2-NC_TRACE_SILK
J2: CONN_041X04_NO_SILK_NO_POP; 1X04_NO_SILK
J4, J6: Vertical Qwiic Connector; JST04_1MM_VERT
LOGO1: SPECIAL_INSTRUCTIONS-ORDERING; ORDERING_INSTRUCTIONS
LOGO2: SFE_LOGO_NAME.1_INCH; SFE_LOGO_NAME_.1
LOGO3: QWIIC_LOGO_3MM; QWIIC_3MM
LOGO4: OSHW-LOGOS; OSHW-LOGO-S
PWR_LED: JUMPER-SMT_2_NC_TRACE_SILK; SMT-JUMPER_2_NC_TRACE_SILK
Q1: 600mA/40V; SOT23-3
R1, R6, R11, R12, R17, R18, R20: 10k; 0603
R2, R13, R16: 75k; 0603
R3, R10, R22, R23: 4.7k; 0603
R4, R9: 124k; 0603
R5: 3.9k; 0603
R7: 2.2M; 0603
R8: 1k; 0603
R14: 220; 0603
R15: 6.8k; 0603
R24: 100k; 0603
TP1, TP2, TP3, TP4, TP5, TP6: TEST-POINT3X5; PAD.03X.05
U5: ULTRASONIC_SENSOR_TRANSMITTER; TFT40-16T
U6: LMV324; SO14
U7: STM8L051F3; TSSOP20
U8: UT3232; TSSOP16
U9: ULTRASONIC_SENSOR_RECEIVER; TCT40-16R

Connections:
3.3V: C2.2, C6.1, C28.1, I2C.2, J2.1, J4.2, J6.2, R8.2, R10.2, R11.2, R12.2, U6.4 (P$V+), U7.P8 (VCC/VREF+), U8.P16 (VCC)
ADDR_RST: TP1.1, U7.P15 (PB5)
DIN1: U7.P11 (PB1), U8.P11 (DIN1)
DIN2: U7.P9 (PD0), U8.P10 (DIN2)
ECHO: J2.3, U7.P12 (PB2)
GND: C2.1, C3.2, C6.2, C15.1, C16.1, C18.2, C26.2, C27.2, C28.2, J2.4, J4.1, J6.1, PWR_LED.1, Q1.2 (E), R5.1, R7.1, R18.2, R20.1, U6.11 (P$V-), U7.P7 (VSS/VREF-), U8.P15 (GND), U9.P2 (2)
INT: Q1.3 (C), R4.2, R8.1, TP6.1, U7.P16 (PB6)
N: R24.2, U7.P14 (PB4)
unnamed: R2.2, R3.1, U6.7 (OUT)
unnamed: C1.1, R2.1, U6.6 (-IN)
unnamed: C1.2, R1.2
unnamed: R3.2, R4.1, U6.3 (+IN)
unnamed: Q1.1 (B), R5.2, R6.2
unnamed: R6.1, U6.1 (OUT)
unnamed: D1.A, R10.1
unnamed: C25.1, U8.P1 (C1+)
unnamed: C12.1, C13.1, R13.1, U6.9 (-IN)
unnamed: C11.2, C12.2, R1.1, R13.2, U6.8 (OUT)
unnamed: D1.C, PWR_LED.2
unnamed: C11.1, C13.2, R14.2, R15.2
unnamed: R15.1, R16.1, U6.14 (OUT)
unnamed: C14.1, R16.2, U6.13 (-IN)
unnamed: C14.2, R17.2
unnamed: I2C.3, R22.2
unnamed: I2C.1, R23.2
unnamed: R17.1, U9.P1 (1)
unnamed: C15.2, C16.2, R9.1, R12.1, R14.1, R18.1, U6.5 (+IN), U6.10 (+IN), U6.12 (+IN)
unnamed: C25.2, U8.P3 (C1-)
unnamed: C24.1, U8.P4 (C2+)
unnamed: C24.2, U8.P5 (C2-)
unnamed: C27.1, U8.P6 (V-)
unnamed: C26.1, U8.P2 (V+)
unnamed: U5.P1 (1), U8.P14 (DOUT1)
unnamed: U5.P2 (2), U8.P7 (DOUT2)
NRST: C18.1, R11.1, TP3.1, U7.P4 (PA1/!RST!)
PB4: C3.1, R7.2, R9.2, R24.1, U6.2 (-IN)
SCL: J4.4, J6.4, R23.1, TP5.1, U7.P19 (PC1)
SDA: J4.3, J6.3, R22.1, TP4.1, U7.P18 (PC0)
SWIM: TP2.1, U7.P3 (PA0)
TRIG: J2.2, R20.2, U7.P13 (PB3)

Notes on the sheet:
Revised By: Elias Santistevan
Microcontroller - STM8L051F3
Testpoints
RS-232 Transceiver - UT3232G Ultrasonic Transmitter - TCT40-16T
OP-AMP - LMV324 Ultrasonic Receiver - TCT40-16R
Qwiic Conncectors
Header
Cut I2C Jumper to disconnect pull up resistors from the I2C lines.
7-bit Unshifted Address : 0x2F
3.3V Only
Power LED
Cut trace to disconnect LED.
High Pass Frequency: 1592 Hz 7.5 Gain
Low Pass Frequency: 31,207Hz High Pass Frequency: 23, 405Hz Gain: 11
High Pass Frequency: 1592Hz Gain: 7.5
Gain: 26

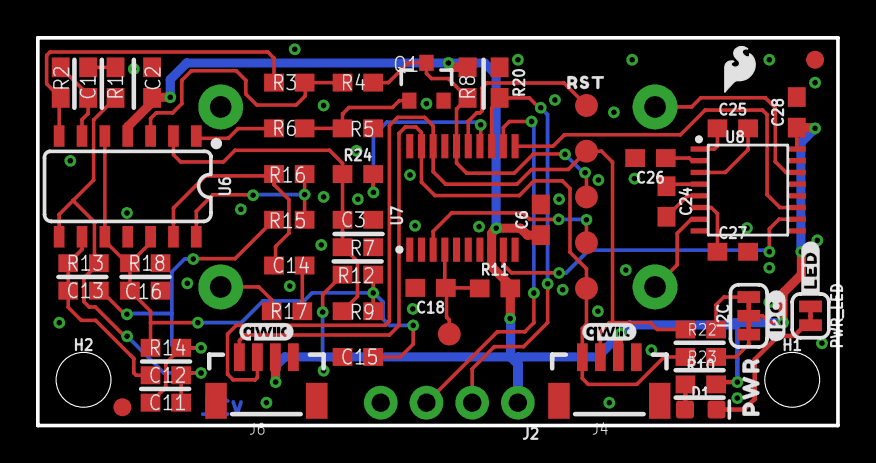
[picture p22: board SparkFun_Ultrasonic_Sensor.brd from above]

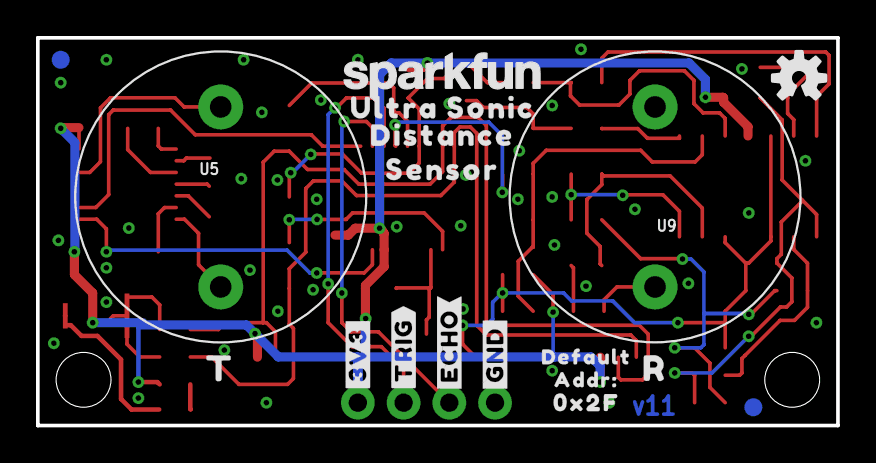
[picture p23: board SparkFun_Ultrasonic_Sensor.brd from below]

Board: 2 copper layers, 44.5 x 21.5 mm, 85 parts (18 on the bottom side), 40 nets.

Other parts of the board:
U$1: #ECHO#0
U$2: #TRIG#1
U$3: #GND#4
U$4: #3V3#2
U$5: QWIIC_3MM
U$6: SFE_LOGO_FLAME_.1
U$7: #I2C#16
U$8: T103
U$9: R104
U$10: DISTANCE101
U$11: ULTRA_SONIC100
U$12: SENSOR102
U$13: DEFAULT129
U$14: ADDR#130
U$15: 0X2F131
U$16: PWR17
U$17: #LED#15
U$18: RST132

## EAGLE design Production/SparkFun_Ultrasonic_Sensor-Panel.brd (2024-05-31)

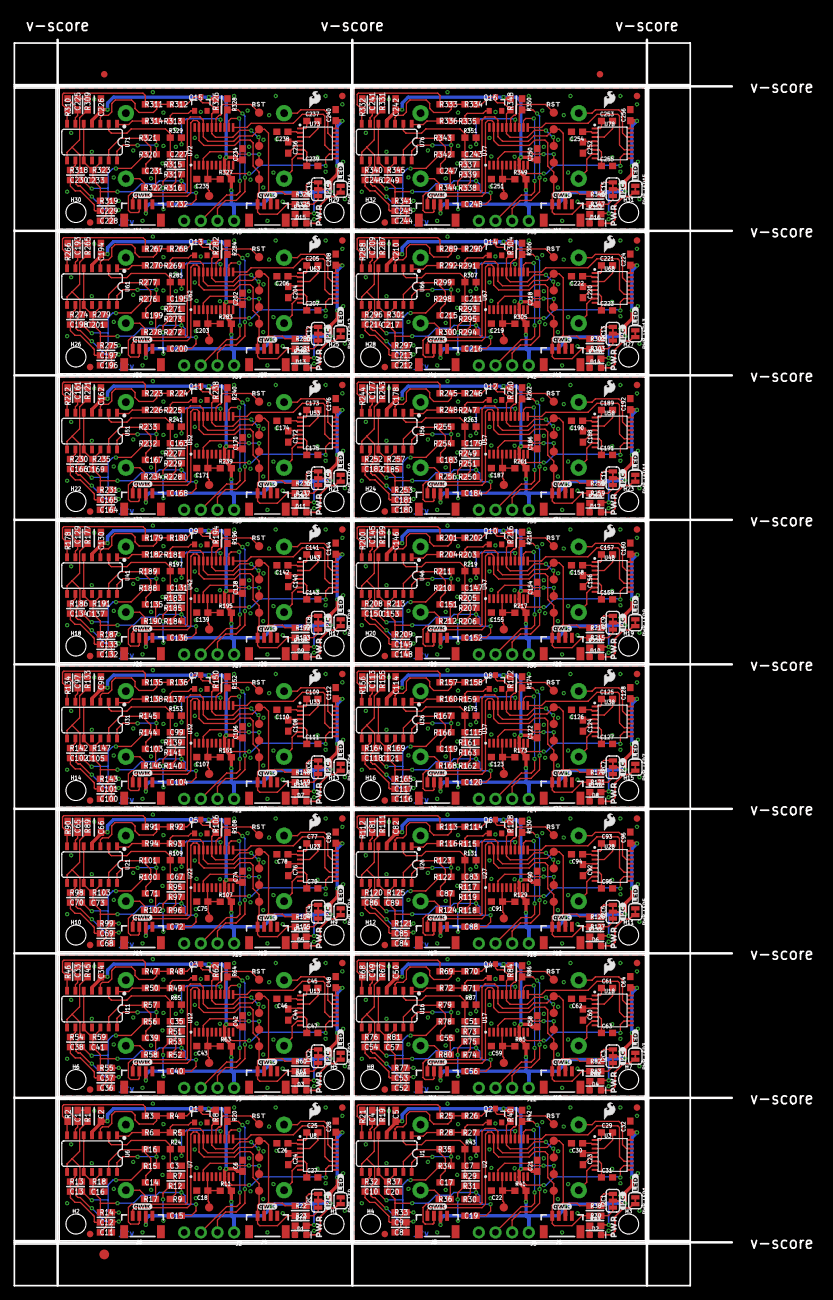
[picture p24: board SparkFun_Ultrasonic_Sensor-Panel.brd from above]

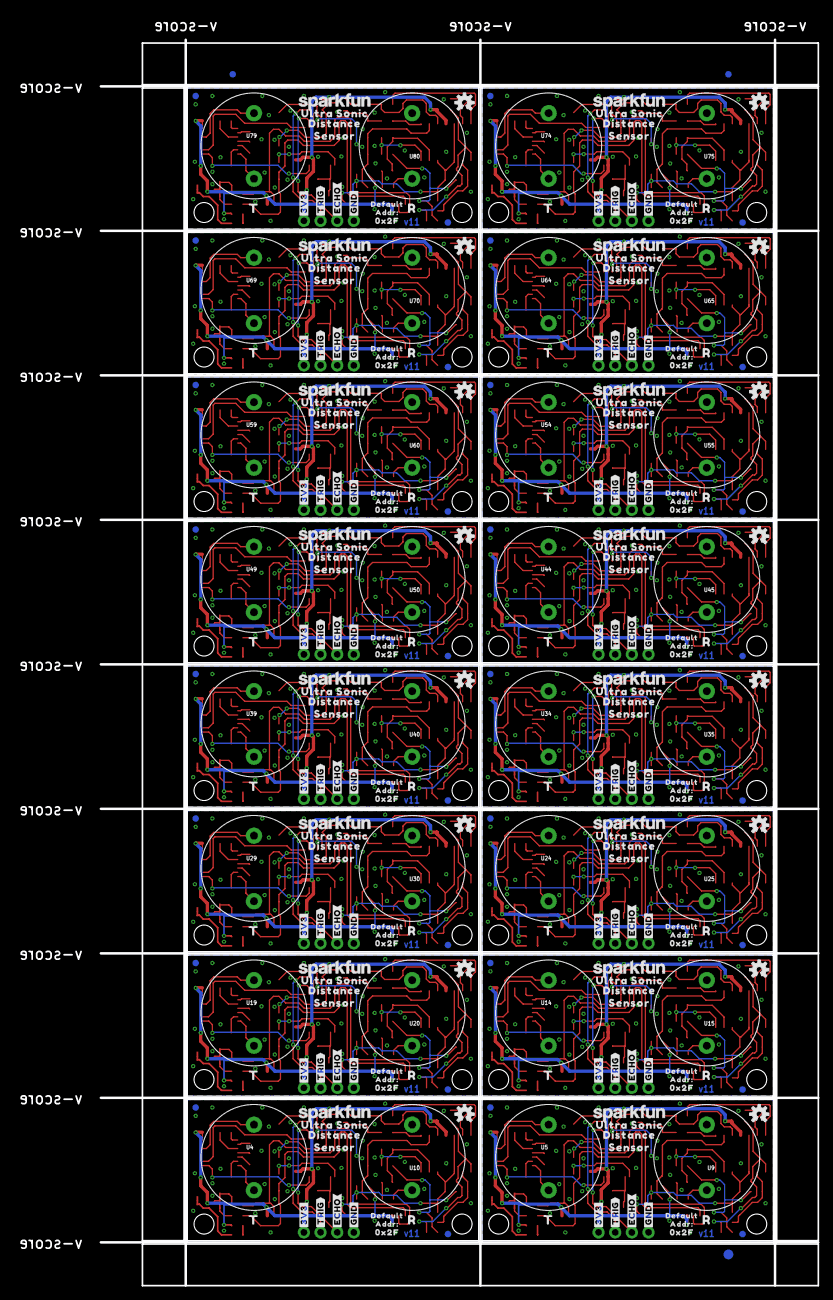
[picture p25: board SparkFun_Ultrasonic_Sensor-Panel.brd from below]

Board: 2 copper layers, 109.5 x 190.1 mm, 1334 parts (291 on the bottom side), 640 nets.

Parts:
C1, C4, C14, C17, C33, C39, C49, C55, C65, C71, C81, C87, C97, C103, C113, C119, C129, C135, C145, C151, C161, C167, C177, C183, C193, C199, C209, C215, C225, C231, C241, C247: 10nF; 0603
C2, C5, C15, C19, C34, C40, C50, C56, C66, C72, C82, C88, C98, C104, C114, C120, C130, C136, C146, C152, C162, C168, C178, C184, C194, C200, C210, C216, C226, C232, C242, C248: 1.0uF; 0603
C3, C7, C8, C10, C11, C13, C16, C20, C35, C36, C38, C41, C51, C52, C54, C57, C67, C68, C70, C73, C83, C84, C86, C89, C99, C100, C102, C105, C115, C116, C118, C121, C131, C132, C134, C137, C147, C148, C150, C153, C163, C164, C166, C169, C179, C180, C182, C185, C195, C196, C198, C201, C211, C212, C214, C217, C227, C228, C230, C233, C243, C244, C246, C249: 1nF; 0603
C6, C18, C21, C22, C23, C24, C25, C26, C27, C28, C29, C30, C31, C32, C42, C43, C44, C45, C46, C47, C48, C58, C59, C60, C61, C62, C63, C64, C74, C75, C76, C77, C78, C79, C80, C90, C91, C92, C93, C94, C95, C96, C106, C107, C108, C109, C110, C111, C112, C122, C123, C124, C125, C126, C127, C128, C138, C139, C140, C141, C142, C143, C144, C154, C155, C156, C157, C158, C159, C160, C170, C171, C172, C173, C174, C175, C176, C186, C187, C188, C189, C190, C191, C192, C202, C203, C204, C205, C206, C207, C208, C218, C219, C220, C221, C222, C223, C224, C234, C235, C236, C237, C238, C239, C240, C250, C251, C252, C253, C254, C255, C256: 0.1uF; 0603
C9, C12, C37, C53, C69, C85, C101, C117, C133, C149, C165, C181, C197, C213, C229, C245: 68pF; 0603
D1, D2, D3, D4, D5, D6, D7, D8, D9, D10, D11, D12, D13, D14, D15, D16: Red; LED-0603
E$1, E$2, E$3, E$4: FIDUCIAL-1X2
E$5, E$6: FIDUCIAL-1.5X3
FD1, FD2, FD3, FD4, FD5, FD6, FD7, FD8, FD9, FD10, FD11, FD12, FD13, FD14, FD15, FD16, FD17, FD18, FD19, FD20, FD21, FD22, FD23, FD24, FD25, FD26, FD27, FD28, FD29, FD30, FD31, FD32, FD33, FD34, FD35, FD36, FD37, FD38, FD39, FD40, FD41, FD42, FD43, FD44, FD45, FD46, FD47, FD48, FD49, FD50, FD51, FD52, FD53, FD54, FD55, FD56, FD57, FD58, FD59, FD60, FD61, FD62, FD63, FD64: FIDUCIAL1X2; FIDUCIAL-1X2
H1, H2, H3, H4, H5, H6, H7, H8, H9, H10, H11, H12, H13, H14, H15, H16, H17, H18, H19, H20, H21, H22, H23, H24, H25, H26, H27, H28, H29, H30, H31, H32: STAND-OFFTIGHT; STAND-OFF-TIGHT
I2C, I2C1, I2C2, I2C3, I2C4, I2C5, I2C6, I2C7, I2C8, I2C9, I2C10, I2C11, I2C12, I2C13, I2C14, I2C15: JUMPER-SMT_3_2-NC_TRACE_SILK; SMT-JUMPER_3_2-NC_TRACE_SILK
J1, J3, J4, J6, J7, J8, J10, J11, J13, J14, J16, J17, J19, J20, J22, J23, J25, J26, J28, J29, J31, J32, J34, J35, J37, J38, J40, J41, J43, J44, J46, J47: Vertical Qwiic Connector; JST04_1MM_VERT
J2, J5, J9, J12, J15, J18, J21, J24, J27, J30, J33, J36, J39, J42, J45, J48: 1X04_NO_SILK
LOGO1, LOGO2, LOGO7, LOGO10, LOGO13, LOGO16, LOGO19, LOGO22, LOGO25, LOGO28, LOGO31, LOGO34, LOGO37, LOGO40, LOGO43, LOGO46: SFE_LOGO_NAME.1_INCH; SFE_LOGO_NAME_.1
LOGO3, LOGO5, LOGO8, LOGO11, LOGO14, LOGO17, LOGO20, LOGO23, LOGO26, LOGO29, LOGO32, LOGO35, LOGO38, LOGO41, LOGO44, LOGO47: QWIIC_LOGO_3MM; QWIIC_3MM
LOGO4, LOGO6, LOGO9, LOGO12, LOGO15, LOGO18, LOGO21, LOGO24, LOGO27, LOGO30, LOGO33, LOGO36, LOGO39, LOGO42, LOGO45, LOGO48: OSHW-LOGOS; OSHW-LOGO-S
PWR_LED, PWR_LED1, PWR_LED2, PWR_LED3, PWR_LED4, PWR_LED5, PWR_LED6, PWR_LED7, PWR_LED8, PWR_LED9, PWR_LED10, PWR_LED11, PWR_LED12, PWR_LED13, PWR_LED14, PWR_LED15: JUMPER-SMT_2_NC_TRACE_SILK; SMT-JUMPER_2_NC_TRACE_SILK
Q1, Q2, Q3, Q4, Q5, Q6, Q7, Q8, Q9, Q10, Q11, Q12, Q13, Q14, Q15, Q16: 600mA/40V; SOT23-3
R1, R6, R11, R12, R17, R18, R19, R20, R28, R31, R36, R37, R41, R42, R45, R50, R53, R58, R59, R63, R64, R67, R72, R75, R80, R81, R85, R86, R89, R94, R97, R102, R103, R107, R108, R111, R116, R119, R124, R125, R129, R130, R133, R138, R141, R146, R147, R151, R152, R155, R160, R163, R168, R169, R173, R174, R177, R182, R185, R190, R191, R195, R196, R199, R204, R207, R212, R213, R217, R218, R221, R226, R229, R234, R235, R239, R240, R243, R248, R251, R256, R257, R261, R262, R265, R270, R273, R278, R279, R283, R284, R287, R292, R295, R300, R301, R305, R306, R309, R314, R317, R322, R323, R327, R328, R331, R336, R339, R344, R345, R349, R350: 10k; 0603
R2, R13, R16, R21, R32, R35, R46, R54, R57, R68, R76, R79, R90, R98, R101, R112, R120, R123, R134, R142, R145, R156, R164, R167, R178, R186, R189, R200, R208, R211, R222, R230, R233, R244, R252, R255, R266, R274, R277, R288, R296, R299, R310, R318, R321, R332, R340, R343: 75k; 0603
R3, R10, R22, R23, R25, R38, R39, R44, R47, R60, R61, R66, R69, R82, R83, R88, R91, R104, R105, R110, R113, R126, R127, R132, R135, R148, R149, R154, R157, R170, R171, R176, R179, R192, R193, R198, R201, R214, R215, R220, R223, R236, R237, R242, R245, R258, R259, R264, R267, R280, R281, R286, R289, R302, R303, R308, R311, R324, R325, R330, R333, R346, R347, R352: 4.7k; 0603
R4, R9, R26, R30, R48, R52, R70, R74, R92, R96, R114, R118, R136, R140, R158, R162, R180, R184, R202, R206, R224, R228, R246, R250, R268, R272, R290, R294, R312, R316, R334, R338: 124k; 0603
R5, R27, R49, R71, R93, R115, R137, R159, R181, R203, R225, R247, R269, R291, R313, R335: 3.9k; 0603
R7, R29, R51, R73, R95, R117, R139, R161, R183, R205, R227, R249, R271, R293, R315, R337: 2.2M; 0603
R8, R40, R62, R84, R106, R128, R150, R172, R194, R216, R238, R260, R282, R304, R326, R348: 1k; 0603
R14, R33, R55, R77, R99, R121, R143, R165, R187, R209, R231, R253, R275, R297, R319, R341: 220; 0603
R15, R34, R56, R78, R100, R122, R144, R166, R188, R210, R232, R254, R276, R298, R320, R342: 6.8k; 0603
R24, R43, R65, R87, R109, R131, R153, R175, R197, R219, R241, R263, R285, R307, R329, R351: 100k; 0603
TP1, TP2, TP3, TP4, TP5, TP6, TP7, TP8, TP9, TP10, TP11, TP12, TP13, TP14, TP15, TP16, TP17, TP18, TP19, TP20, TP21, TP22, TP23, TP24, TP25, TP26, TP27, TP28, TP29, TP30, TP31, TP32, TP33, TP34, TP35, TP36, TP37, TP38, TP39, TP40, TP41, TP42, TP43, TP44, TP45, TP46, TP47, TP48, TP49, TP50, TP51, TP52, TP53, TP54, TP55, TP56, TP57, TP58, TP59, TP60, TP61, TP62, TP63, TP64, TP65, TP66, TP67, TP68, TP69, TP70, TP71, TP72, TP73, TP74, TP75, TP76, TP77, TP78, TP79, TP80, TP81, TP82, TP83, TP84, TP85, TP86, TP87, TP88, TP89, TP90, TP91, TP92, TP93, TP94, TP95, TP96: TEST-POINT3X5; PAD.03X.05
U1, U6, U11, U16, U21, U26, U31, U36, U41, U46, U51, U56, U61, U66, U71, U76: LMV324; SO14
U2, U7, U12, U17, U22, U27, U32, U37, U42, U47, U52, U57, U62, U67, U72, U77: STM8L051F3; TSSOP20
U3, U8, U13, U18, U23, U28, U33, U38, U43, U48, U53, U58, U63, U68, U73, U78: SP3232EB; TSSOP16
U4, U5, U14, U19, U24, U29, U34, U39, U44, U49, U54, U59, U64, U69, U74, U79: ULTRASONIC_SENSOR_TRANSMITTER; CUSA-T80
U9, U10, U15, U20, U25, U30, U35, U40, U45, U50, U55, U60, U65, U70, U75, U80: ULTRASONIC_SENSOR_RECEIVER; CUSA-R80
U$1, U$19, U$37, U$55, U$73, U$91, U$109, U$127, U$145, U$163, U$181, U$199, U$217, U$235, U$253, U$271: #ECHO#0
U$2, U$20, U$38, U$56, U$74, U$92, U$110, U$128, U$146, U$164, U$182, U$200, U$218, U$236, U$254, U$272: #TRIG#1
U$3, U$26, U$44, U$62, U$80, U$98, U$116, U$134, U$152, U$170, U$188, U$206, U$224, U$242, U$260, U$278: #GND#4
U$4, U$27, U$45, U$63, U$81, U$99, U$117, U$135, U$153, U$171, U$189, U$207, U$225, U$243, U$261, U$279: #3V3#2
U$5, U$28, U$46, U$64, U$82, U$100, U$118, U$136, U$154, U$172, U$190, U$208, U$226, U$244, U$262, U$280: QWIIC_3MM
U$6, U$29, U$47, U$65, U$83, U$101, U$119, U$137, U$155, U$173, U$191, U$209, U$227, U$245, U$263, U$281: SFE_LOGO_FLAME_.1
U$7, U$30, U$48, U$66, U$84, U$102, U$120, U$138, U$156, U$174, U$192, U$210, U$228, U$246, U$264, U$282: #I2C#16
U$8, U$21, U$39, U$57, U$75, U$93, U$111, U$129, U$147, U$165, U$183, U$201, U$219, U$237, U$255, U$273: T103
U$9, U$22, U$40, U$58, U$76, U$94, U$112, U$130, U$148, U$166, U$184, U$202, U$220, U$238, U$256, U$274: R104
U$10, U$23, U$41, U$59, U$77, U$95, U$113, U$131, U$149, U$167, U$185, U$203, U$221, U$239, U$257, U$275: DISTANCE101
U$11, U$24, U$42, U$60, U$78, U$96, U$114, U$132, U$150, U$168, U$186, U$204, U$222, U$240, U$258, U$276: ULTRA_SONIC100
U$12, U$25, U$43, U$61, U$79, U$97, U$115, U$133, U$151, U$169, U$187, U$205, U$223, U$241, U$259, U$277: SENSOR102
U$13, U$31, U$49, U$67, U$85, U$103, U$121, U$139, U$157, U$175, U$193, U$211, U$229, U$247, U$265, U$283: DEFAULT129
U$14, U$32, U$50, U$68, U$86, U$104, U$122, U$140, U$158, U$176, U$194, U$212, U$230, U$248, U$266, U$284: ADDR#130
U$15, U$33, U$51, U$69, U$87, U$105, U$123, U$141, U$159, U$177, U$195, U$213, U$231, U$249, U$267, U$285: 0X2F131
U$16, U$34, U$52, U$70, U$88, U$106, U$124, U$142, U$160, U$178, U$196, U$214, U$232, U$250, U$268, U$286: PWR17
U$17, U$35, U$53, U$71, U$89, U$107, U$125, U$143, U$161, U$179, U$197, U$215, U$233, U$251, U$269, U$287: #LED#15
U$18, U$36, U$54, U$72, U$90, U$108, U$126, U$144, U$162, U$180, U$198, U$216, U$234, U$252, U$270, U$288: RST132

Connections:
3.3V: C2.2, C6.1, C28.1, I2C.2, J2.1, J4.2, J6.2, R8.2, R10.2, R11.2, R12.2, U6.4, U7.P8, U8.P16
3.3V1: C5.2, C21.1, C32.1, I2C1.2, J1.2, J3.2, J5.1, R31.2, R40.2, R41.2, R44.2, U1.4, U2.P8, U3.P16
3.3V2: C34.2, C42.1, C48.1, I2C2.2, J7.2, J8.2, J9.1, R53.2, R62.2, R63.2, R66.2, U11.4, U12.P8, U13.P16
3.3V3: C50.2, C58.1, C64.1, I2C3.2, J10.2, J11.2, J12.1, R75.2, R84.2, R85.2, R88.2, U16.4, U17.P8, U18.P16
3.3V4: C66.2, C74.1, C80.1, I2C4.2, J13.2, J14.2, J15.1, R97.2, R106.2, R107.2, R110.2, U21.4, U22.P8, U23.P16
3.3V5: C82.2, C90.1, C96.1, I2C5.2, J16.2, J17.2, J18.1, R119.2, R128.2, R129.2, R132.2, U26.4, U27.P8, U28.P16
3.3V6: C98.2, C106.1, C112.1, I2C6.2, J19.2, J20.2, J21.1, R141.2, R150.2, R151.2, R154.2, U31.4, U32.P8, U33.P16
3.3V7: C114.2, C122.1, C128.1, I2C7.2, J22.2, J23.2, J24.1, R163.2, R172.2, R173.2, R176.2, U36.4, U37.P8, U38.P16
3.3V8: C130.2, C138.1, C144.1, I2C8.2, J25.2, J26.2, J27.1, R185.2, R194.2, R195.2, R198.2, U41.4, U42.P8, U43.P16
3.3V9: C146.2, C154.1, C160.1, I2C9.2, J28.2, J29.2, J30.1, R207.2, R216.2, R217.2, R220.2, U46.4, U47.P8, U48.P16
3.3V10: C162.2, C170.1, C176.1, I2C10.2, J31.2, J32.2, J33.1, R229.2, R238.2, R239.2, R242.2, U51.4, U52.P8, U53.P16
3.3V11: C178.2, C186.1, C192.1, I2C11.2, J34.2, J35.2, J36.1, R251.2, R260.2, R261.2, R264.2, U56.4, U57.P8, U58.P16
3.3V12: C194.2, C202.1, C208.1, I2C12.2, J37.2, J38.2, J39.1, R273.2, R282.2, R283.2, R286.2, U61.4, U62.P8, U63.P16
3.3V13: C210.2, C218.1, C224.1, I2C13.2, J40.2, J41.2, J42.1, R295.2, R304.2, R305.2, R308.2, U66.4, U67.P8, U68.P16
3.3V14: C226.2, C234.1, C240.1, I2C14.2, J43.2, J44.2, J45.1, R317.2, R326.2, R327.2, R330.2, U71.4, U72.P8, U73.P16
3.3V15: C242.2, C250.1, C256.1, I2C15.2, J46.2, J47.2, J48.1, R339.2, R348.2, R349.2, R352.2, U76.4, U77.P8, U78.P16
ADDR_RST: TP1.1, U7.P15
ADDR_RST1: TP7.1, U2.P15
ADDR_RST2: TP13.1, U12.P15
ADDR_RST3: TP19.1, U17.P15
ADDR_RST4: TP25.1, U22.P15
ADDR_RST5: TP31.1, U27.P15
ADDR_RST6: TP37.1, U32.P15
ADDR_RST7: TP43.1, U37.P15
ADDR_RST8: TP49.1, U42.P15
ADDR_RST9: TP55.1, U47.P15
ADDR_RST10: TP61.1, U52.P15
ADDR_RST11: TP67.1, U57.P15
ADDR_RST12: TP73.1, U62.P15
ADDR_RST13: TP79.1, U67.P15
ADDR_RST14: TP85.1, U72.P15
ADDR_RST15: TP91.1, U77.P15
DIN1: U7.P11, U8.P11
DIN2: U7.P9, U8.P10
DIN3: U2.P9, U3.P10
DIN4: U2.P11, U3.P11
DIN5: U12.P9, U13.P10
DIN6: U12.P11, U13.P11
DIN7: U17.P9, U18.P10
DIN8: U17.P11, U18.P11
DIN9: U22.P9, U23.P10
DIN10: U22.P11, U23.P11
DIN11: U27.P9, U28.P10
DIN12: U27.P11, U28.P11
DIN13: U32.P9, U33.P10
DIN14: U32.P11, U33.P11
DIN15: U37.P9, U38.P10
DIN16: U37.P11, U38.P11
DIN17: U42.P9, U43.P10
DIN18: U42.P11, U43.P11
DIN19: U47.P9, U48.P10
DIN20: U47.P11, U48.P11
DIN21: U52.P9, U53.P10
DIN22: U52.P11, U53.P11
DIN23: U57.P9, U58.P10
DIN24: U57.P11, U58.P11
DIN25: U62.P9, U63.P10
DIN26: U62.P11, U63.P11
DIN27: U67.P9, U68.P10
DIN28: U67.P11, U68.P11
DIN29: U72.P9, U73.P10
DIN30: U72.P11, U73.P11
DIN31: U77.P9, U78.P10
DIN32: U77.P11, U78.P11
ECHO: J2.3, U7.P12
ECHO1: J5.3, U2.P12
ECHO2: J9.3, U12.P12
ECHO3: J12.3, U17.P12
ECHO4: J15.3, U22.P12
ECHO5: J18.3, U27.P12
ECHO6: J21.3, U32.P12
ECHO7: J24.3, U37.P12
ECHO8: J27.3, U42.P12
ECHO9: J30.3, U47.P12
ECHO10: J33.3, U52.P12
ECHO11: J36.3, U57.P12
ECHO12: J39.3, U62.P12
ECHO13: J42.3, U67.P12
ECHO14: J45.3, U72.P12
ECHO15: J48.3, U77.P12
GND: C2.1, C3.2, C6.2, C15.1, C16.1, C18.2, C26.2, C27.2, C28.2, J2.4, J4.1, J6.1, PWR_LED.1, Q1.2, R5.1, R7.1, R18.2, R20.1, U6.11, U7.P7, U8.P15, U9.P2
GND1: C5.1, C7.2, C19.1, C20.1, C21.2, C22.2, C30.2, C31.2, C32.2, J1.1, J3.1, J5.4, PWR_LED1.1, Q2.2, R27.1, R29.1, R37.2, R42.1, U1.11, U2.P7, U3.P15, U10.P2
GND2: C34.1, C35.2, C40.1, C41.1, C42.2, C43.2, C46.2, C47.2, C48.2, J7.1, J8.1, J9.4, PWR_LED2.1, Q3.2, R49.1, R51.1, R59.2, R64.1, U11.11, U12.P7, U13.P15, U15.P2
GND3: C50.1, C51.2, C56.1, C57.1, C58.2, C59.2, C62.2, C63.2, C64.2, J10.1, J11.1, J12.4, PWR_LED3.1, Q4.2, R71.1, R73.1, R81.2, R86.1, U16.11, U17.P7, U18.P15, U20.P2
GND4: C66.1, C67.2, C72.1, C73.1, C74.2, C75.2, C78.2, C79.2, C80.2, J13.1, J14.1, J15.4, PWR_LED4.1, Q5.2, R93.1, R95.1, R103.2, R108.1, U21.11, U22.P7, U23.P15, U25.P2
GND5: C82.1, C83.2, C88.1, C89.1, C90.2, C91.2, C94.2, C95.2, C96.2, J16.1, J17.1, J18.4, PWR_LED5.1, Q6.2, R115.1, R117.1, R125.2, R130.1, U26.11, U27.P7, U28.P15, U30.P2
GND6: C98.1, C99.2, C104.1, C105.1, C106.2, C107.2, C110.2, C111.2, C112.2, J19.1, J20.1, J21.4, PWR_LED6.1, Q7.2, R137.1, R139.1, R147.2, R152.1, U31.11, U32.P7, U33.P15, U35.P2
GND7: C114.1, C115.2, C120.1, C121.1, C122.2, C123.2, C126.2, C127.2, C128.2, J22.1, J23.1, J24.4, PWR_LED7.1, Q8.2, R159.1, R161.1, R169.2, R174.1, U36.11, U37.P7, U38.P15, U40.P2
GND8: C130.1, C131.2, C136.1, C137.1, C138.2, C139.2, C142.2, C143.2, C144.2, J25.1, J26.1, J27.4, PWR_LED8.1, Q9.2, R181.1, R183.1, R191.2, R196.1, U41.11, U42.P7, U43.P15, U45.P2
GND9: C146.1, C147.2, C152.1, C153.1, C154.2, C155.2, C158.2, C159.2, C160.2, J28.1, J29.1, J30.4, PWR_LED9.1, Q10.2, R203.1, R205.1, R213.2, R218.1, U46.11, U47.P7, U48.P15, U50.P2
GND10: C162.1, C163.2, C168.1, C169.1, C170.2, C171.2, C174.2, C175.2, C176.2, J31.1, J32.1, J33.4, PWR_LED10.1, Q11.2, R225.1, R227.1, R235.2, R240.1, U51.11, U52.P7, U53.P15, U55.P2
GND11: C178.1, C179.2, C184.1, C185.1, C186.2, C187.2, C190.2, C191.2, C192.2, J34.1, J35.1, J36.4, PWR_LED11.1, Q12.2, R247.1, R249.1, R257.2, R262.1, U56.11, U57.P7, U58.P15, U60.P2
GND12: C194.1, C195.2, C200.1, C201.1, C202.2, C203.2, C206.2, C207.2, C208.2, J37.1, J38.1, J39.4, PWR_LED12.1, Q13.2, R269.1, R271.1, R279.2, R284.1, U61.11, U62.P7, U63.P15, U65.P2
GND13: C210.1, C211.2, C216.1, C217.1, C218.2, C219.2, C222.2, C223.2, C224.2, J40.1, J41.1, J42.4, PWR_LED13.1, Q14.2, R291.1, R293.1, R301.2, R306.1, U66.11, U67.P7, U68.P15, U70.P2
GND14: C226.1, C227.2, C232.1, C233.1, C234.2, C235.2, C238.2, C239.2, C240.2, J43.1, J44.1, J45.4, PWR_LED14.1, Q15.2, R313.1, R315.1, R323.2, R328.1, U71.11, U72.P7, U73.P15, U75.P2
GND15: C242.1, C243.2, C248.1, C249.1, C250.2, C251.2, C254.2, C255.2, C256.2, J46.1, J47.1, J48.4, PWR_LED15.1, Q16.2, R335.1, R337.1, R345.2, R350.1, U76.11, U77.P7, U78.P15, U80.P2
INT: Q1.3, R4.2, R8.1, TP6.1, U7.P16
INT1: Q2.3, R26.2, R40.1, TP12.1, U2.P16
INT2: Q3.3, R48.2, R62.1, TP18.1, U12.P16
INT3: Q4.3, R70.2, R84.1, TP24.1, U17.P16
INT4: Q5.3, R92.2, R106.1, TP30.1, U22.P16
INT5: Q6.3, R114.2, R128.1, TP36.1, U27.P16
INT6: Q7.3, R136.2, R150.1, TP42.1, U32.P16
INT7: Q8.3, R158.2, R172.1, TP48.1, U37.P16
INT8: Q9.3, R180.2, R194.1, TP54.1, U42.P16
INT9: Q10.3, R202.2, R216.1, TP60.1, U47.P16
INT10: Q11.3, R224.2, R238.1, TP66.1, U52.P16
INT11: Q12.3, R246.2, R260.1, TP72.1, U57.P16
INT12: Q13.3, R268.2, R282.1, TP78.1, U62.P16
INT13: Q14.3, R290.2, R304.1, TP84.1, U67.P16
INT14: Q15.3, R312.2, R326.1, TP90.1, U72.P16
INT15: Q16.3, R334.2, R348.1, TP96.1, U77.P16
N: R24.2, U7.P14
N1: R43.2, U2.P14
N2: R65.2, U12.P14
N3: R87.2, U17.P14
N4: R109.2, U22.P14
N5: R131.2, U27.P14
N6: R153.2, U32.P14
N7: R175.2, U37.P14
N8: R197.2, U42.P14
N9: R219.2, U47.P14
N10: R241.2, U52.P14
N11: R263.2, U57.P14
N12: R285.2, U62.P14
N13: R307.2, U67.P14
N14: R329.2, U72.P14
N15: R351.2, U77.P14
unnamed: R2.2, R3.1, U6.7
unnamed: C1.1, R2.1, U6.6
unnamed: C1.2, R1.2
unnamed: R3.2, R4.1, U6.3
unnamed: Q1.1, R5.2, R6.2
unnamed: R6.1, U6.1
unnamed: D1.A, R10.1
unnamed: C25.1, U8.P1
unnamed: C12.1, C13.1, R13.1, U6.9
unnamed: C11.2, C12.2, R1.1, R13.2, U6.8
unnamed: D1.C, PWR_LED.2
unnamed: C11.1, C13.2, R14.2, R15.2
unnamed: R21.2, R25.1, U1.7
unnamed: R15.1, R16.1, U6.14
unnamed: C14.1, R16.2, U6.13
unnamed: C14.2, R17.2
unnamed: C4.1, R21.1, U1.6
unnamed: C4.2, R19.2
unnamed: I2C.3, R22.2
unnamed: I2C.1, R23.2
unnamed: R25.2, R26.1, U1.3
unnamed: Q2.1, R27.2, R28.2
unnamed: R28.1, U1.1
unnamed: C9.1, C10.1, R32.1, U1.9
unnamed: C8.2, C9.2, R19.1, R32.2, U1.8
unnamed: R17.1, U9.P1
unnamed: C8.1, C10.2, R33.2, R34.2
unnamed: R34.1, R35.1, U1.14
unnamed: C17.1, R35.2, U1.13
unnamed: C17.2, R36.2
unnamed: C15.2, C16.2, R9.1, R12.1, R14.1, R18.1, U6.5, U6.10, U6.12
unnamed: I2C1.3, R38.2
unnamed: I2C1.1, R39.2
unnamed: R36.1, U10.P1
unnamed: C29.1, U3.P1
unnamed: C29.2, U3.P3
unnamed: C25.2, U8.P3
unnamed: C24.1, U8.P4
unnamed: C24.2, U8.P5
unnamed: C27.1, U8.P6
unnamed: C26.1, U8.P2
unnamed: C23.1, U3.P4
unnamed: C23.2, U3.P5
unnamed: C31.1, U3.P6
unnamed: C30.1, U3.P2
unnamed: U3.P14, U4.P1
unnamed: U3.P7, U4.P2
unnamed: U5.P1, U8.P14
unnamed: U5.P2, U8.P7
unnamed: C19.2, C20.2, R30.1, R31.1, R33.1, R37.1, U1.5, U1.10, U1.12
unnamed: D2.A, R44.1
unnamed: D2.C, PWR_LED1.2
unnamed: R46.2, R47.1, U11.7
unnamed: C33.1, R46.1, U11.6
unnamed: C33.2, R45.2
unnamed: R47.2, R48.1, U11.3
unnamed: Q3.1, R49.2, R50.2
unnamed: R50.1, U11.1
unnamed: C37.1, C38.1, R54.1, U11.9
unnamed: C36.2, C37.2, R45.1, R54.2, U11.8
unnamed: C36.1, C38.2, R55.2, R56.2
unnamed: R56.1, R57.1, U11.14
unnamed: C39.1, R57.2, U11.13
unnamed: C39.2, R58.2
unnamed: I2C2.3, R60.2
unnamed: I2C2.1, R61.2
unnamed: R58.1, U15.P1
unnamed: C45.1, U13.P1
unnamed: C45.2, U13.P3
unnamed: C44.1, U13.P4
unnamed: C44.2, U13.P5
unnamed: C47.1, U13.P6
unnamed: C46.1, U13.P2
unnamed: U13.P14, U14.P1
unnamed: U13.P7, U14.P2
unnamed: C40.2, C41.2, R52.1, R53.1, R55.1, R59.1, U11.5, U11.10, U11.12
unnamed: D3.A, R66.1
unnamed: D3.C, PWR_LED2.2
unnamed: R68.2, R69.1, U16.7
unnamed: C49.1, R68.1, U16.6
unnamed: C49.2, R67.2
unnamed: R69.2, R70.1, U16.3
unnamed: Q4.1, R71.2, R72.2
unnamed: R72.1, U16.1
unnamed: C53.1, C54.1, R76.1, U16.9
unnamed: C52.2, C53.2, R67.1, R76.2, U16.8
unnamed: C52.1, C54.2, R77.2, R78.2
unnamed: R78.1, R79.1, U16.14
unnamed: C55.1, R79.2, U16.13
unnamed: C55.2, R80.2
unnamed: I2C3.3, R82.2
unnamed: I2C3.1, R83.2
unnamed: R80.1, U20.P1
unnamed: C61.1, U18.P1
unnamed: C61.2, U18.P3
unnamed: C60.1, U18.P4
unnamed: C60.2, U18.P5
unnamed: C63.1, U18.P6
unnamed: C62.1, U18.P2
unnamed: U18.P14, U19.P1
unnamed: U18.P7, U19.P2
unnamed: C56.2, C57.2, R74.1, R75.1, R77.1, R81.1, U16.5, U16.10, U16.12
unnamed: D4.A, R88.1
unnamed: D4.C, PWR_LED3.2
unnamed: R90.2, R91.1, U21.7
unnamed: C65.1, R90.1, U21.6
unnamed: C65.2, R89.2
unnamed: R91.2, R92.1, U21.3
unnamed: Q5.1, R93.2, R94.2
unnamed: R94.1, U21.1
unnamed: C69.1, C70.1, R98.1, U21.9
unnamed: C68.2, C69.2, R89.1, R98.2, U21.8
unnamed: C68.1, C70.2, R99.2, R100.2
unnamed: R100.1, R101.1, U21.14
unnamed: C71.1, R101.2, U21.13
unnamed: C71.2, R102.2
unnamed: I2C4.3, R104.2
unnamed: I2C4.1, R105.2
unnamed: R102.1, U25.P1
unnamed: C77.1, U23.P1
unnamed: C77.2, U23.P3
unnamed: C76.1, U23.P4
unnamed: C76.2, U23.P5
unnamed: C79.1, U23.P6
unnamed: C78.1, U23.P2
unnamed: U23.P14, U24.P1
unnamed: U23.P7, U24.P2
unnamed: C72.2, C73.2, R96.1, R97.1, R99.1, R103.1, U21.5, U21.10, U21.12
unnamed: D5.A, R110.1
unnamed: D5.C, PWR_LED4.2
unnamed: R112.2, R113.1, U26.7
unnamed: C81.1, R112.1, U26.6
unnamed: C81.2, R111.2
unnamed: R113.2, R114.1, U26.3
unnamed: Q6.1, R115.2, R116.2
unnamed: R116.1, U26.1
unnamed: C85.1, C86.1, R120.1, U26.9
unnamed: C84.2, C85.2, R111.1, R120.2, U26.8
unnamed: C84.1, C86.2, R121.2, R122.2
unnamed: R122.1, R123.1, U26.14
unnamed: C87.1, R123.2, U26.13
unnamed: C87.2, R124.2
unnamed: I2C5.3, R126.2
unnamed: I2C5.1, R127.2
unnamed: R124.1, U30.P1
unnamed: C93.1, U28.P1
unnamed: C93.2, U28.P3
unnamed: C92.1, U28.P4
unnamed: C92.2, U28.P5
unnamed: C95.1, U28.P6
unnamed: C94.1, U28.P2
unnamed: U28.P14, U29.P1
unnamed: U28.P7, U29.P2
unnamed: C88.2, C89.2, R118.1, R119.1, R121.1, R125.1, U26.5, U26.10, U26.12
unnamed: D6.A, R132.1
unnamed: D6.C, PWR_LED5.2
unnamed: R134.2, R135.1, U31.7
unnamed: C97.1, R134.1, U31.6
unnamed: C97.2, R133.2
unnamed: R135.2, R136.1, U31.3
unnamed: Q7.1, R137.2, R138.2
unnamed: R138.1, U31.1
unnamed: C101.1, C102.1, R142.1, U31.9
unnamed: C100.2, C101.2, R133.1, R142.2, U31.8
unnamed: C100.1, C102.2, R143.2, R144.2
unnamed: R144.1, R145.1, U31.14
unnamed: C103.1, R145.2, U31.13
unnamed: C103.2, R146.2
unnamed: I2C6.3, R148.2
unnamed: I2C6.1, R149.2
unnamed: R146.1, U35.P1
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

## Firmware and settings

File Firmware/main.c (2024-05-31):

/*
 * SparkFun Ulrasonic Distance Sensor
 *
 * SPDX-License-Identifier: MIT
 *
 * Copyright (c) 2024 SparkFun Electronics
 */

#include "main.h"
#include "STM8L15x_StdPeriph_Driver/inc/stm8l15x.h"
#include "STM8L15x_StdPeriph_Driver/inc/stm8l15x_exti.h"
#include "STM8L15x_StdPeriph_Driver/inc/stm8l15x_flash.h"
#include "STM8L15x_StdPeriph_Driver/inc/stm8l15x_gpio.h"
#include "STM8L15x_StdPeriph_Driver/inc/stm8l15x_i2c.h"
#include "STM8L15x_StdPeriph_Driver/inc/stm8l15x_tim2.h"

// Variables are used for interrupt flags
volatile uint8_t outRangeFlag = 0;
volatile uint8_t opAmpInterrupt = 0;
volatile uint8_t addressInterrupt = 0;
volatile uint8_t triggerInterrupt = 0;
volatile uint8_t i2cInterrupt = 0;

uint8_t volatile distanceH = 0, distanceL = 0;
uint8_t userAddress = 0x2F;
uint16_t cycles = 0; 

volatile uint8_t peripheralBuffer[kBufferSize] = {0};

// Needed for ST's perhiperhal Flash library memory functions.
#ifdef _COSMIC_
int _fctcpy(char name);
#endif /*_COSMIC_*/

int main(void)
{

    initializeCLK();
    initializeTimers();
    initializeGPIO();

    // Before initlizing I2C, check if the EEPROM has been written to. If not, write the default address.
    if (getAddr() == kDefaultEEPROMValue)
        setAddr(kDefaultUltrasonicAddress);

    // This function reads the I2C address written to EEPROM
    initializeI2C();

    enableInterrupts();
    setOpAmp(kDisableOpAmp);

    while (1)
    {

        // I2C Interrupt Flag Check and only two commands are supported: Read Distance and Change Address.
        if (i2cInterrupt == 1)
        {
            i2cInterrupt = 0;
            if (peripheralBuffer[0] == kCmdReadDistance)
            {
                setOpAmp(kEnableOpAmp);
                pulseTransmitter();
            }
            else if (peripheralBuffer[0] == kCmdChangeAddress &&
                     (peripheralBuffer[1] >= kI2CAddressMin && peripheralBuffer[1] < kI2CAddressMax))
            {
                userAddress = peripheralBuffer[1];
                if (userAddress != getAddr())
                {
                    setAddr(userAddress);
                    initializeI2C();
                }
            }
        }

        // Op-Amp Interrupt Flag Check which indicates that a Transmit pulse has been sensed by
        // the Receiver and the time can now be calculated.
        if (opAmpInterrupt == 1)
        {
            opAmpInterrupt = 0;
            cycles = TIM2_GetCounter();
            TIM2_Cmd(DISABLE);
            TIM3_Cmd(DISABLE);
            GPIO_SetBits(GPIOB, GPIO_Pin_2);

            if (outRangeFlag == 0)
            {
                // time = time per cycle(in seconds) * number of cycles
                double distance =
                    (kTIM2CycleSeconds * (double)cycles * (double)kSpeedOfSound * (double)kConvertMM) / 2.0;
                distanceH = (uint16_t)(distance) >> 8;
                distanceL = (uint8_t)distance;
            }
            else
            {
                distanceH = 0;
                distanceL = 0;
            }
            outRangeFlag = 0;
        }

        // Trigger Interrupt Flag Check, this allows for starting a distance measurement without
        // I2C communication, note that the distance still needs to be read over I2C.
        if (triggerInterrupt == 1)
        {
            triggerInterrupt = 0;
            if (GPIO_ReadInputDataBit(GPIOB, GPIO_Pin_3))
            {
                setOpAmp(kEnableOpAmp);
                pulseTransmitter();
                TIM3_SetCounter(0);
                TIM3_Cmd(ENABLE);
            }
        }

        // Address Interrupt Flag Check.
        // Write the default address to EEPROM and reinitialize I2C.
        if (addressInterrupt == 1)
        {
            addressInterrupt = 0;
            setAddr(kDefaultUltrasonicAddress);
            initializeI2C();
        }
    }
}

/*
 * @brief  delay function.
 * @param  n : the number of cylces to delay: ~15873 cycles per ms at 16MHz.
 * @retval None
 */
void delay(uint16_t n)
{
    while (n--)
        ;
}

/*
 * @brief GPIO setup for the ultrasonic sensor: DIN1, DIN2, ECHO, PB4 and interrupts pins TRIG, INT, and ADDR_RST.
 * @param  None
 * @retval None
 */
void initializeGPIO(void)
{
    GPIO_Init(GPIOD, (GPIO_Pin_TypeDef)GPIO_Pin_0, GPIO_Mode_Out_PP_High_Fast); // DIN2
    GPIO_Init(GPIOB, (GPIO_Pin_TypeDef)GPIO_Pin_1, GPIO_Mode_Out_PP_High_Fast); // DIN1
    GPIO_Init(GPIOB, (GPIO_Pin_TypeDef)GPIO_Pin_2, GPIO_Mode_Out_PP_Low_Fast);  // ECHO
    GPIO_Init(GPIOB, (GPIO_Pin_TypeDef)GPIO_Pin_4, GPIO_Mode_Out_PP_Low_Slow);  // PB4
    GPIO_Init(GPIOB, (GPIO_Pin_TypeDef)GPIO_Pin_3, GPIO_Mode_In_FL_IT);         // TRIG
    GPIO_Init(GPIOB, (GPIO_Pin_TypeDef)GPIO_Pin_5, GPIO_Mode_In_PU_IT);         // ADDR_RST
    GPIO_Init(GPIOB, (GPIO_Pin_TypeDef)GPIO_Pin_6, GPIO_Mode_In_FL_IT);         // INT

    // External interrups for TRIG, INT, ADDR_RST
    EXTI_DeInit();
    EXTI_SetPinSensitivity(EXTI_Pin_3, EXTI_Trigger_Rising);  // TRIG
    EXTI_SetPinSensitivity(EXTI_Pin_5, EXTI_Trigger_Falling); // ADDR_RST
    EXTI_SetPinSensitivity(EXTI_Pin_6, EXTI_Trigger_Rising);  // INT
}

/*
 * @brief 7-bit I2C setup for the ultrasonic sensor.
 * @param  None
 * @retval None
 */
void initializeI2C(void)
{
    CLK_PeripheralClockConfig(CLK_Peripheral_I2C1, ENABLE);
    I2C_DeInit(I2C1);
    I2C_Init(I2C1, kI2CSpeed, getAddr(), I2C_Mode_I2C, I2C_DutyCycle_2, I2C_Ack_Enable, I2C_AcknowledgedAddress_7bit);
    I2C_ITConfig(I2C1, (I2C_IT_TypeDef)(I2C_IT_ERR | I2C_IT_EVT | I2C_IT_BUF), ENABLE);
    I2C_Cmd(I2C1, ENABLE);
}

/*
 * @brief Setup for the 16MHz internal High Speed Clock for the STM8L051F3.
 * @param  None
 * @retval None
 */
void initializeCLK(void)
{
    CLK_SYSCLKSourceConfig(CLK_SYSCLKSource_HSI);
    CLK_SYSCLKDivConfig(CLK_SYSCLKDiv_1);
    CLK_HSICmd(ENABLE);
    while (CLK_GetFlagStatus(CLK_FLAG_HSIRDY) == RESET)
        ;
}

/*
 * @brief Enables and configures timers two, three, and four used for distance calculations, trigger timeout, and
 * enabling the op-amp respectively.
 * @param  None
 * @retval None
 */
void initializeTimers(void)
{

    // Clock used for calculating the transmitter's pulse distance.
    // Prescalar sets timer to 125kHz.
    // Period is the maximum allowed time for a 16 bit timer, which sets
    // its' overflow around 524ms.
    TIM2_DeInit();
    CLK_PeripheralClockConfig(CLK_Peripheral_TIM2, ENABLE);
    TIM2_TimeBaseInit(TIM2_Prescaler_128, TIM2_CounterMode_Up, kTim2Period);
    TIM2_ClearFlag(TIM2_FLAG_Update);
    TIM2_ITConfig(TIM2_IT_Update, ENABLE);

    // Clock used for determining time out with regards to the trigger pin.
    // Prescalar sets timer to 125kHz.
    // Period is the maximum allowed time for a 16 bit timer, which puts 
    // its' overflow around 524ms.
    TIM3_DeInit();
    CLK_PeripheralClockConfig(CLK_Peripheral_TIM3, ENABLE);
    TIM3_TimeBaseInit(TIM3_Prescaler_128, TIM3_CounterMode_Up, kTim3Period);
    TIM3_ClearFlag(TIM3_FLAG_Update);
    TIM3_ITConfig(TIM3_IT_Update, ENABLE);

    // Clock used to delay floating the inverting pin on the last stage (comparator)
    // of the op-amp.
    // Prescalar sets timer to 125kHz.
    // The period is set to ~1ms. 
    TIM4_DeInit();
    CLK_PeripheralClockConfig(CLK_Peripheral_TIM4, ENABLE);
    TIM4_TimeBaseInit(TIM4_Prescaler_128, kTim4Period);
    TIM4_ClearFlag(TIM4_FLAG_Update);
    TIM4_ITConfig(TIM4_IT_Update, ENABLE);
}

/*
 * @brief Pulse the transmitter at ~48kHz by toggling the pins on the transmitter.
 * @param  None
 * @retval None
 */
void pulseTransmitter(void)
{

    uint8_t i = 0;

    // Set pins to opposite states in case they aren't already.
    GPIO_ResetBits(GPIOB, GPIO_Pin_1);
    GPIO_SetBits(GPIOD, GPIO_Pin_0);

    // Sends 8 pulses at 48kHz by toggling the transmitter pins
    // in opposite states.
    for (i = 0; i < 8; i++)
    {
        GPIO_ResetBits(GPIOD, GPIO_Pin_0);
        GPIO_SetBits(GPIOB, GPIO_Pin_1);

        delay(kCycles48kHz);

        GPIO_SetBits(GPIOD, GPIO_Pin_0);
        GPIO_ResetBits(GPIOB, GPIO_Pin_1);

        delay(kCycles48kHz);
    }
    // ECHO pin high
    GPIO_ResetBits(GPIOB, GPIO_Pin_2);
    TIM2_SetCounter(0);
    TIM4_SetCounter(0);
    TIM2_Cmd(ENABLE);
    TIM4_Cmd(ENABLE);
}

/*
 * @brief Enable or disable the op-amp. The inverting pin of the op-amp changes state often, so it's
 * reinitialized each time it's enabled/disabled.
 * @param  enable: 1 to enable, 0 to disable.
 * @retval None
 */
void setOpAmp(uint8_t enable)
{
    if (enable)
    {
        GPIO_Init(GPIOB, (GPIO_Pin_TypeDef)GPIO_Pin_4, GPIO_Mode_Out_PP_Low_Fast); // PB4
        GPIO_ResetBits(GPIOB, GPIO_Pin_4);
    }
    else
    {
        GPIO_Init(GPIOB, (GPIO_Pin_TypeDef)GPIO_Pin_4, GPIO_Mode_Out_PP_Low_Fast); // PB4
        GPIO_SetBits(GPIOB, GPIO_Pin_4);
    }
}

/*
 * @brief Write the given I2C address to EEPROM.
 * @param  userAddr: The given I2C address for the Ultrasonic sensor.
 * @retval None
 */
void setAddr(uint8_t userAddr)
{

    FLASH_DeInit();
    FLASH_SetProgrammingTime(FLASH_ProgramTime_Standard);

    FLASH_Unlock(FLASH_MemType_Program);
    while (FLASH_GetFlagStatus(FLASH_FLAG_PUL) == RESET)
        ;

    FLASH_Unlock(FLASH_MemType_Data);
    while (FLASH_GetFlagStatus(FLASH_FLAG_DUL) == RESET)
        ;

    FLASH_ProgramByte(FLASH_DATA_EEPROM_START_PHYSICAL_ADDRESS, userAddr);

    while (FLASH_GetFlagStatus(FLASH_FLAG_HVOFF) == RESET)
        ;

    FLASH_Lock(FLASH_MemType_Data);
    FLASH_Lock(FLASH_MemType_Program);
}

/*
 * @brief Read the ultarsonic's I2C address byte from the EEPROM.
 * @retval The I2C address of the Ultrasonic sensor.
 */
uint8_t getAddr(void)
{

    uint8_t addr = 0;

    FLASH_DeInit();
    FLASH_SetProgrammingTime(FLASH_ProgramTime_Standard);

    FLASH_Unlock(FLASH_MemType_Program);
    while (FLASH_GetFlagStatus(FLASH_FLAG_PUL) == RESET)
        ;

    FLASH_Unlock(FLASH_MemType_Data);
    while (FLASH_GetFlagStatus(FLASH_FLAG_DUL) == RESET)
        ;

    addr = FLASH_ReadByte(FLASH_DATA_EEPROM_START_PHYSICAL_ADDRESS);

    FLASH_Lock(FLASH_MemType_Data);
    FLASH_Lock(FLASH_MemType_Program);

    return addr;
}

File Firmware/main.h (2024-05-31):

/*
 * SparkFun Ulrasonic Distance Sensor
 *
 * SPDX-License-Identifier: MIT
 *
 * Copyright (c) 2024 SparkFun Electronics
 */

#ifndef _ULTRASONIC_MAIN_H
#define _ULTRASONIC_MAIN_H

#include "STM8L15x_StdPeriph_Driver/inc/stm8l15x_exti.h"
#include "STM8L15x_StdPeriph_Driver/inc/stm8l15x_gpio.h"
#include "stm8l15x.h"

// I2C related variables
#define kBufferSize 4
#define kI2CSpeed 100000
#define kDefaultUltrasonicAddress (0x2F << 1)
#define kDefaultEEPROMValue 0x00
#define kCmdReadDistance 0x01
#define kCmdChangeAddress 0x04
#define kI2CAddressMin 0x07
#define kI2CAddressMax 0x7F

// Op-Amp related variables
#define kDisableOpAmp 0x00
#define kEnableOpAmp 0x01

// Timer period values
#define kTim2Period 0xFFFF //65535 or 524ms using 128 prescaler
// Prescaler value allows for about a 1ms time period.
#define kTIM2Prescaler 128 // ~1ms
#define kTim3Period 0xFFFF //65535 or 524ms using 128 prescaler
#define kTim4Period 0x7C

// High Speed Internal Clock (HSI) value (16 MHz)
#define kHSIClock 16000000

// Variables used for calculating distance
#define kSpeedOfSound 343.0 // Speed of sound in m/s at 20 degrees Celsius
#define kTIM2CycleTime (kHSIClock / kTIM2Prescaler)
#define kConvertMM 1000
#define kCycles48kHz 15
#define kTIM2CycleSeconds (1.0 / (double)kTIM2CycleTime)

void delay(uint16_t n);
void initializeGPIO(void);
void initializeI2C(void);
void initializeCLK(void);
void initializeTimers(void);
void pulseTransmitter(void);
void setOpAmp(uint8_t enable);
void setAddr(uint8_t userAddr);
uint8_t getAddr(void);

#endif

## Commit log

2023-12-07 Original design commit
    [Zio Ultrasonic Distance Sensor.GBL, Zio Ultrasonic Distance Sensor.GBO, Zio Ultrasonic Distance Sensor.GBP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]
2024-01-10 Removes old gerbers, adds some new parts
    [Zio Ultrasonic Distance Sensor.GBL, Zio Ultrasonic Distance Sensor.GBO, Zio Ultrasonic Distance Sensor.GBP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]
2024-01-10 Adds new ultrasonic receiver and transmitter and new RS232 IC
2024-01-11 Renames folders
    [Zio Ultrasonic Distance Sensor.brd, Zio Ultrasonic Distance Sensor.sch]
2024-01-11 Renames hardware files
    [SparkFun_Ultrasonic_Sensor.brd, SparkFun_Ultrasonic_Sensor.sch]
2024-01-11 Adds tkeepout to ultrasonic sensors
2024-01-12 Removes almost any lingering parts from old design. Gets close to finishing schematic
    [SparkFun_Ultrasonic_Sensor.brd, SparkFun_Ultrasonic_Sensor.sch]
2024-01-12 Finishes up schematic
    [SparkFun_Ultrasonic_Sensor.brd, SparkFun_Ultrasonic_Sensor.sch]
2024-01-12 Moves passives around the PCB
    [SparkFun_Ultrasonic_Sensor.brd, SparkFun_Ultrasonic_Sensor.sch]
2024-01-12 Moves design to origin, routes most signals
    [SparkFun_Ultrasonic_Sensor.brd]
2024-01-12 Routes more wires
    [SparkFun_Ultrasonic_Sensor.brd, SparkFun_Ultrasonic_Sensor.sch]
2024-01-15 Finishes routing the board.
    [SparkFun_Ultrasonic_Sensor.brd]
2024-01-15 Adds more vias
    [SparkFun_Ultrasonic_Sensor.brd]
2024-01-15 Adds silk
    [SparkFun_Ultrasonic_Sensor.brd, SparkFun_Ultrasonic_Sensor.sch]
2024-01-15 Adds ordering instructions
    [SparkFun_Ultrasonic_Sensor.brd]
2024-01-15 Adds measures
    [SparkFun_Ultrasonic_Sensor.brd]
2024-01-15 Changes the size and placement of parts so that they sit at reasonable dimensions
    [SparkFun_Ultrasonic_Sensor.brd, SparkFun_Ultrasonic_Sensor.sch]
2024-01-15 Moves SparkFun logo
    [SparkFun_Ultrasonic_Sensor.brd]
2024-01-15 Adds a few more measures
    [SparkFun_Ultrasonic_Sensor.brd]
2024-01-15 Adds version number
    [SparkFun_Ultrasonic_Sensor.brd]
2024-01-15 Moves the odering instructions away from the design
    [SparkFun_Ultrasonic_Sensor.brd]
2024-01-16 Fixes various schematic elements, some acid traps, and improves ground pour
    [SparkFun_Ultrasonic_Sensor.brd, SparkFun_Ultrasonic_Sensor.sch]
2024-01-16 Moves a number of parts to away from the Ultrasonic sensor plated holes
    [SparkFun_Ultrasonic_Sensor.brd]
2024-01-16 Moves some more parts away from the sensor through holes and updates the schematic
    [SparkFun_Ultrasonic_Sensor.brd, SparkFun_Ultrasonic_Sensor.sch]
2024-01-22 Adds power LED, RXT silk, and increases the size of the tespoints.
    [SparkFun_Ultrasonic_Sensor.brd, SparkFun_Ultrasonic_Sensor.sch]
2024-01-22 Adds parts with new SKUs to design
    [SparkFun_Ultrasonic_Sensor.brd, SparkFun_Ultrasonic_Sensor.sch]
2024-01-22 Adds some silk
    [SparkFun_Ultrasonic_Sensor.brd]
2024-01-22 Adds Production Files
    [SparkFun_Ultrasonic_Sensor-Panel.GBL, SparkFun_Ultrasonic_Sensor-Panel.GBO, SparkFun_Ultrasonic_Sensor-Panel.GBP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]
2024-01-30 Adds some notes on the op-amp stages
    [SparkFun_Ultrasonic_Sensor.sch]
2024-01-30 Adds some better spacing
    [SparkFun_Ultrasonic_Sensor.sch]
2024-03-04 Puts the interrups files in the correct directory
    [stm8l15x_it.c]
2024-03-04 Adds interrupt vector file - many of the handlers will need to be removed
2024-03-04 Updates interrupts and pins
2024-03-05 Files are linking, but there is simply too many items .text size overflow error
    [main.c, stm8l15x_it.c]
2024-03-05 Comments out various libraries that I'm not using
    [firmware_v01.stp]
2024-03-07 Reduces the size of many libraries so that it fits onto the MCU
    [firmware_v01.stp]
2024-03-07 Removes the I2C function and replaces it with API calls
    [firmware_v01.stp]
2024-03-09 Rewrites I2C interrupt function
2024-04-08 various changes, many missed commits later
    [main.c, stm8l15x_it.c]
2024-04-29 Updates the board files with the new part names
    [SparkFun_Ultrasonic_Sensor.brd, SparkFun_Ultrasonic_Sensor.sch]
2024-04-30 Debugging update
    [firmware_v01.stp]
2024-04-30 Removes bsp files, moves functions to main, adds main.h
    * Reduces the size of the code within the interrupts
    * Adds interrupt flags for the numerous interrupts
    * Moves all actions to the main loop
2024-04-30 Adds function for enabling and setting timers
2024-04-30 Updates prototype names for functions defined in main
2024-04-30 Updates the interrupt variable names to better understand what they are
2024-04-30 Replaces command variables with better naming convention
    [main.c, main.h, stm8l15x_it.c]
2024-05-01 Fixes multiple defintions of symbol error
    * variables were being shared between two files and logically I thought to include the same header file across to .c files. This however, was causing the variable to be compiled by TWO translation units (two c files) thus redefining the variable.
    [firmware_v01.stp]
2024-05-01 fixes the various naming conventions of constants and functions
    [main.c, main.h, stm8l15x_it.c]
2024-05-01 Fixes unchanged variables to the upated ones
    [main.c, stm8l15x_it.c]
2024-05-05 Uses switch/case in i2c interrupt, increases i2c speed to 100kHz
2024-05-15 Fixes the interrupt vector table
    [main.c, main.h, stm8_interrupt_vector.c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]
2024-05-21 Ensures all timers work
2024-05-22 Fixes delay in pulsetransmitter
    [main.c, stm8l15x_it.c]
2024-05-22 changes some variable names, updates functions for changing the i2c address.
2024-05-23 Removes another magic number, fixes some floating point integer operations
    [main.c, main.h, stm8l15x_it.c]
2024-05-23 Fixes the #define bug where I forgot parentheses which led to unknown behavior
    [main.c, main.h, stm8l15x_tim2.c]
2024-05-24 Updates code to reflect the pin used on new design
2024-05-24 Renames examples, fixes to trigger based readings
    [main.c, stm8l15x_it.c]
2024-05-25 Removes old hex file, updates design with correct pin names on RS-232 transceiver
    [SparkFun_Ultrasonic_Sensor.sch]
2024-05-26 Fixes trigger interrupt
2024-05-28 Removes arduino examples - moved to arduino library repository
2024-05-31 Adds volatile to variables that need it, adds more comments
    * Updates the name of some variable to indicate they're flags
    * Moves interrupt variables to the top of the code block they trigger
    * Swaps the ECHO pin polarity for consistency with the older product
    [main.c, main.h, stm8l15x_it.c]
2024-05-31 Fix to cycles declaration and fix to echo pin orientation
    [main.c, stm8l15x_it.c]
2024-06-13 Adding Hardware Assembly photo
2024-06-13 Updating schematic and files and intro
2024-06-20 Adding Arduino Library link
2024-06-20 Updating sensor range
2024-06-21 Fixes link to Arduino library
2024-07-12 Redirect deleted branch to "main" in Arduino Library so GitHub Pages can deploy properly

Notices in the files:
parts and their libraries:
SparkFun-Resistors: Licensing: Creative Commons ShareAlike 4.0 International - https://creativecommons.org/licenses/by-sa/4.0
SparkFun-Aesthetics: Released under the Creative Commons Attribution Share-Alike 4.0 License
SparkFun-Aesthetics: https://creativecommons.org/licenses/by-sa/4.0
